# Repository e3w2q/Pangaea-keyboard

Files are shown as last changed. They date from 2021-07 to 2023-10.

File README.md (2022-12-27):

# Pangaea





Parts adjustable keyboard

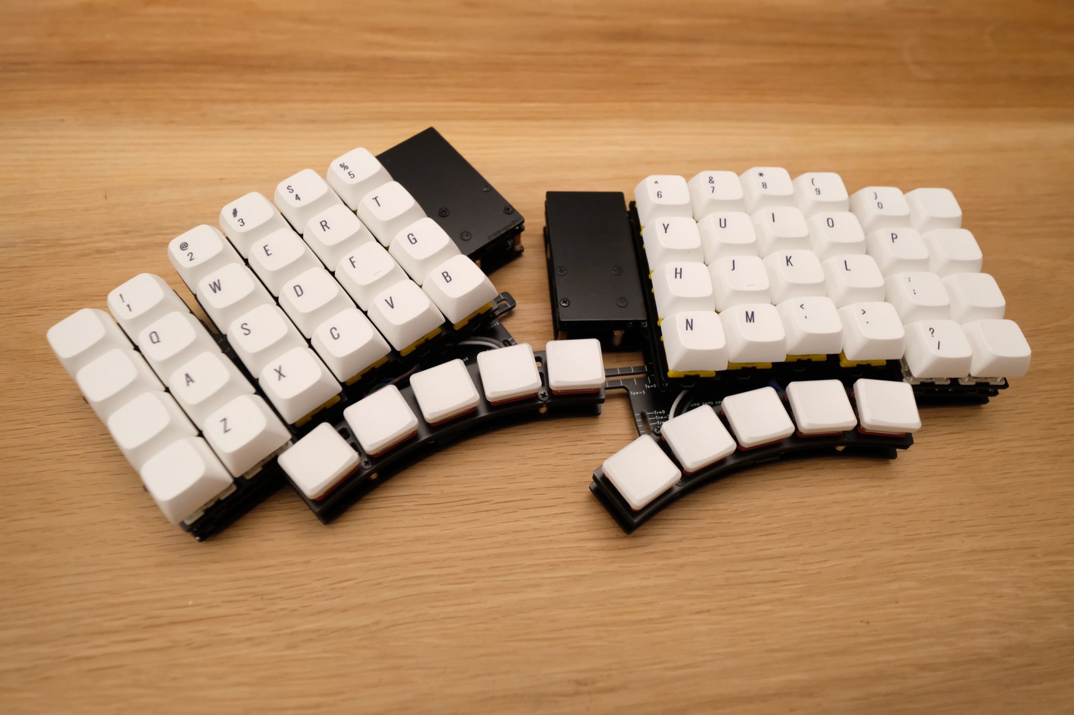
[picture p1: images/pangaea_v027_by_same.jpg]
pangaea_v027_by_same


## What is Pangaea?

Column staggered keyboards differ in the way the columns are shifted and the thumb keys are placed, depending on the designer's assumed finger size and design philosophy.

Pangaea is a column staggered keyboard that allows you to adjust the key layout for the pinky and thumb areas.

https://user-images.githubusercontent.com/50942793/145424793-fb12e412-2e66-4725-97fb-f4ba11a33d6f.mp4

## Link

[ホワイトペーパー](whitepaper_jp.md), [White Paper](whitepaper_en.md)

[ビルドガイド](build_guide_jp.md), [Build Guide](build_guide_en.md)

[パーツリスト](bom_list_jp.md)

[Firmware](firmware/)

[PCB](design/)

[Gerbers](products/)

## License

* firmware: GPLv3
* Garber files: CC-BY-NC
* other files: MIT

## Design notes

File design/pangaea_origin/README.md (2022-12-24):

# Pangaea PCB Data

Some design data are not included.

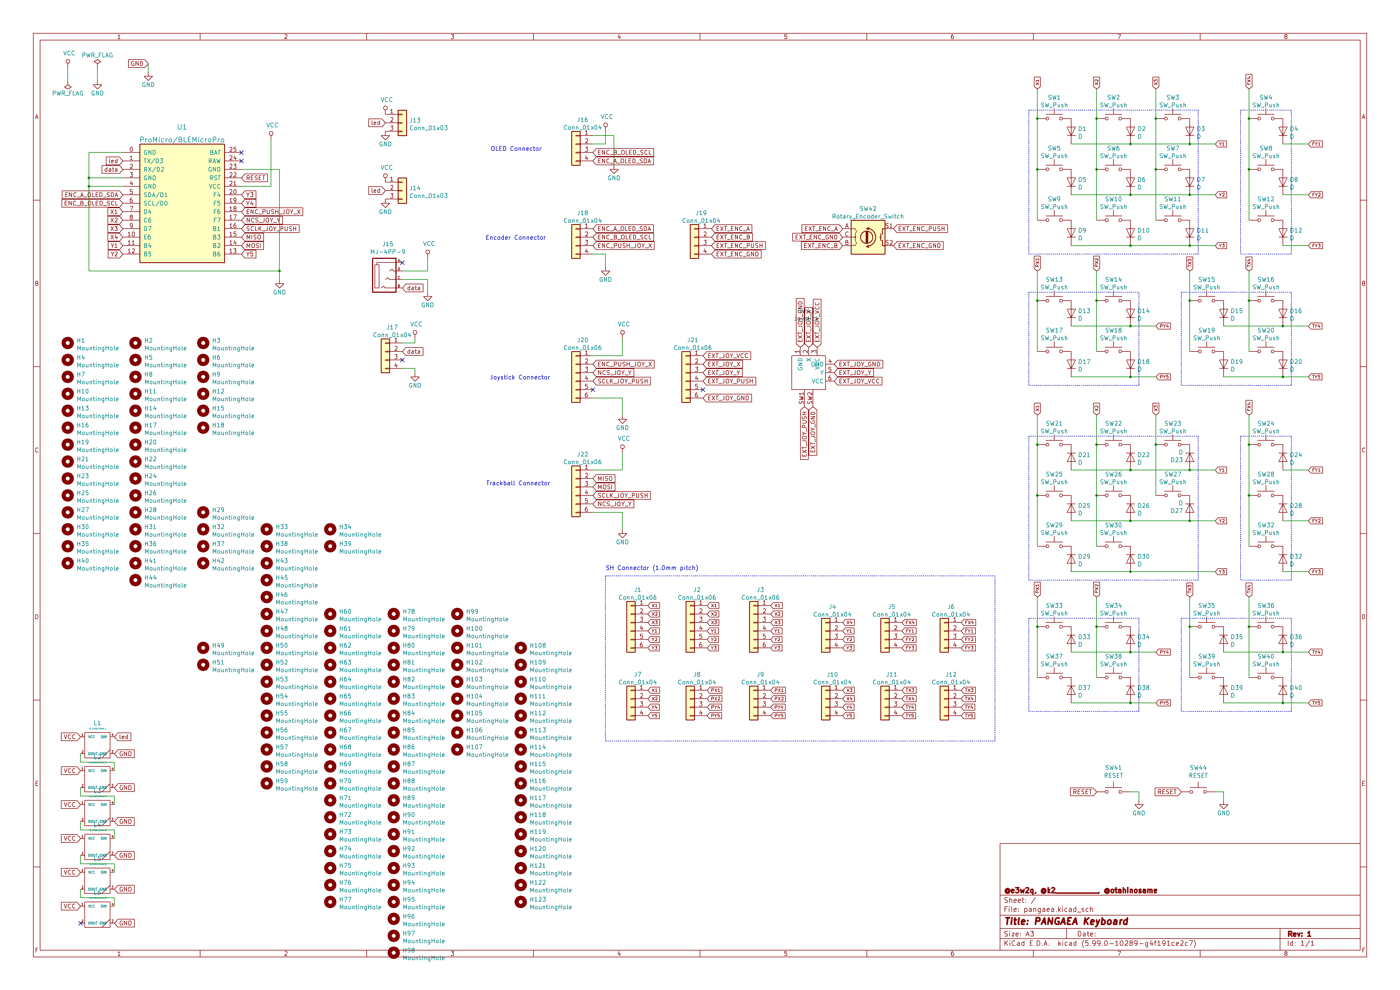
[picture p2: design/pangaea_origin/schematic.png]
Schematic


“Further, we have to be prepared always for the possibility that each new discovery, no matter what science furnishes it, may modify the conclusions we draw.” 

Alfred Wegener, *The Origins of Continents and Oceans*

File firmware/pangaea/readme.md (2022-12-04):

# Panagaea Keybaord

This is a modular type split keyboard consisting of three parts: main keys, pinkeys, and thumb keys. The name comes from the ancient continents, each of which shows a separate continent. As a feature, it has a mechanism to adjust the position of those modules. Furthermore, Pangaea defines specifications for creating extended components so that you can combine components or create new ones.

The firmware is written with QMK.

Keyboard Maintainer:
  [@otahinosame](https://twitter.com/otahinosame), [@e3w2q](https://twitter.com/e3w2q), and [@k2___________](https://twitter.com/@k2___________)

## How to build
```
$ qmk compile -kb pangaea -km default
```

The default keymap is tested with QMK Firmware 0.18.17. (Nov 27, 2022)

Limitations:
 - Only left side rotatay encoder supported.
 - No push button of the rotatay encoder implemented.

## How to flash
```
$ qmk flash -kb pangaea -km default
```

If you want to try to use other keymaps, for example,

```
$ qmk flash -kb pangaea -km otahinosame
```

Please refer the details in keymaps directory.

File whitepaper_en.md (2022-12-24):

Date: 2022/12/24
Keyboard Maintainer: [@otahinosame](https://twitter.com/otahinosame), [@e3w2q](https://twitter.com/e3w2q), and [@k2___________](https://twitter.com/@k2___________)

*Note: This text is an English translation of [White Paper written in Japanese](https://github.com/e3w2q/Pangaea-keyboard/blob/main/whitepaper_jp.md).

# What’s Pangaea?

Pangaea is a keyboard that isolates the key layout into several “islands” and allows the user to move the position of each island freely.   As an island, it is divided into three parts: the main body, the thumb section, and the little finger section.  We named it Pangaea, comparing the movement of a chunk of the key arrangement to the theory of continental drift.

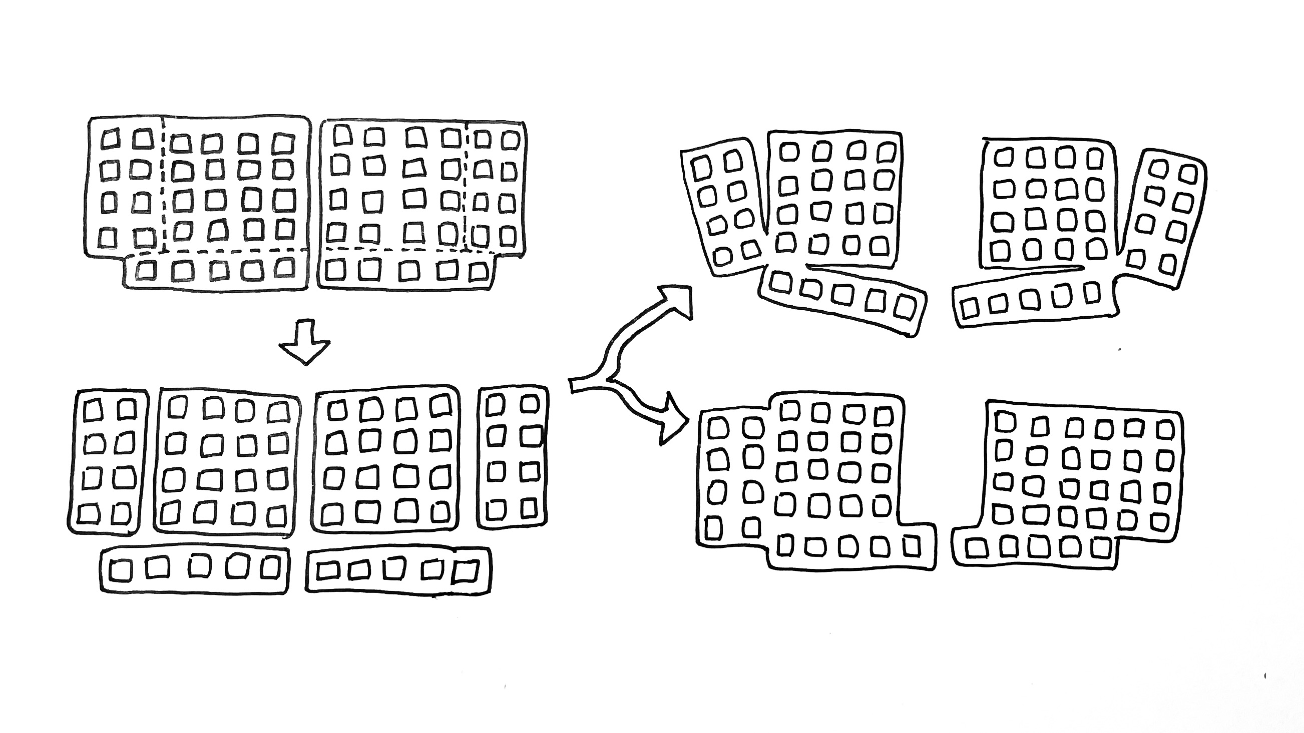
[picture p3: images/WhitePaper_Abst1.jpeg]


# What can it do?

By moving the island, you can adjust the key layout to suit your preference and hand shape. Just as you adjust the seat height and back angle of a chair while checking its comfort, you can adjust the keyboard to a shape that is easy to use while using it.

# Why Pangaea?

What was it made for?
Original experience (by @otahinosame)

There are various column-staggered keyboards, but the differences that interest me are the height of the little finger and the position of the thumb keys. However, you won’t know which one fits you until you try it out. If you want to try a little layout changes in actual usage, it costs a certain money to make it.  I want to at least make sure how high it fits before I buy the kit. (I want to avoid local solutions, I want to avoid bias since I’ve just bought it, I want to actually compare and decide.)

# What kind of things do we want?

I want a keyboard that can be easily adjusted while in use. I want a kit that can easily make keyboards with adjustable key layouts. Everyone wants it! That’s how we came to develop this kit.

# How Pangaea works?

Relative positions of islands are connected with connecting parts. They can be freely movable or fixed. For example, by combining plates with slits on the rails, the position and angle can be continuously adjusted. 

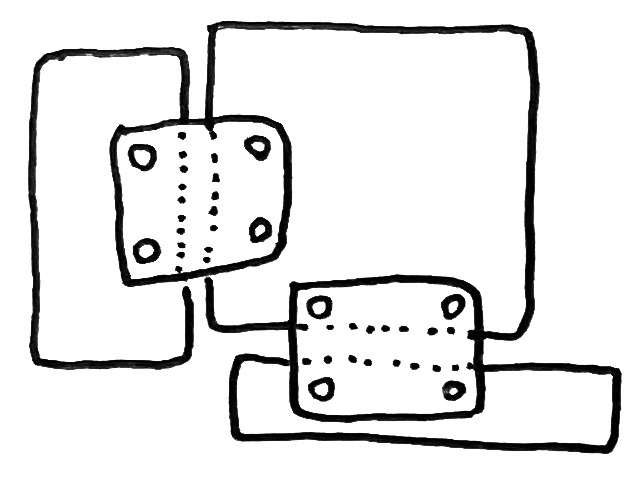
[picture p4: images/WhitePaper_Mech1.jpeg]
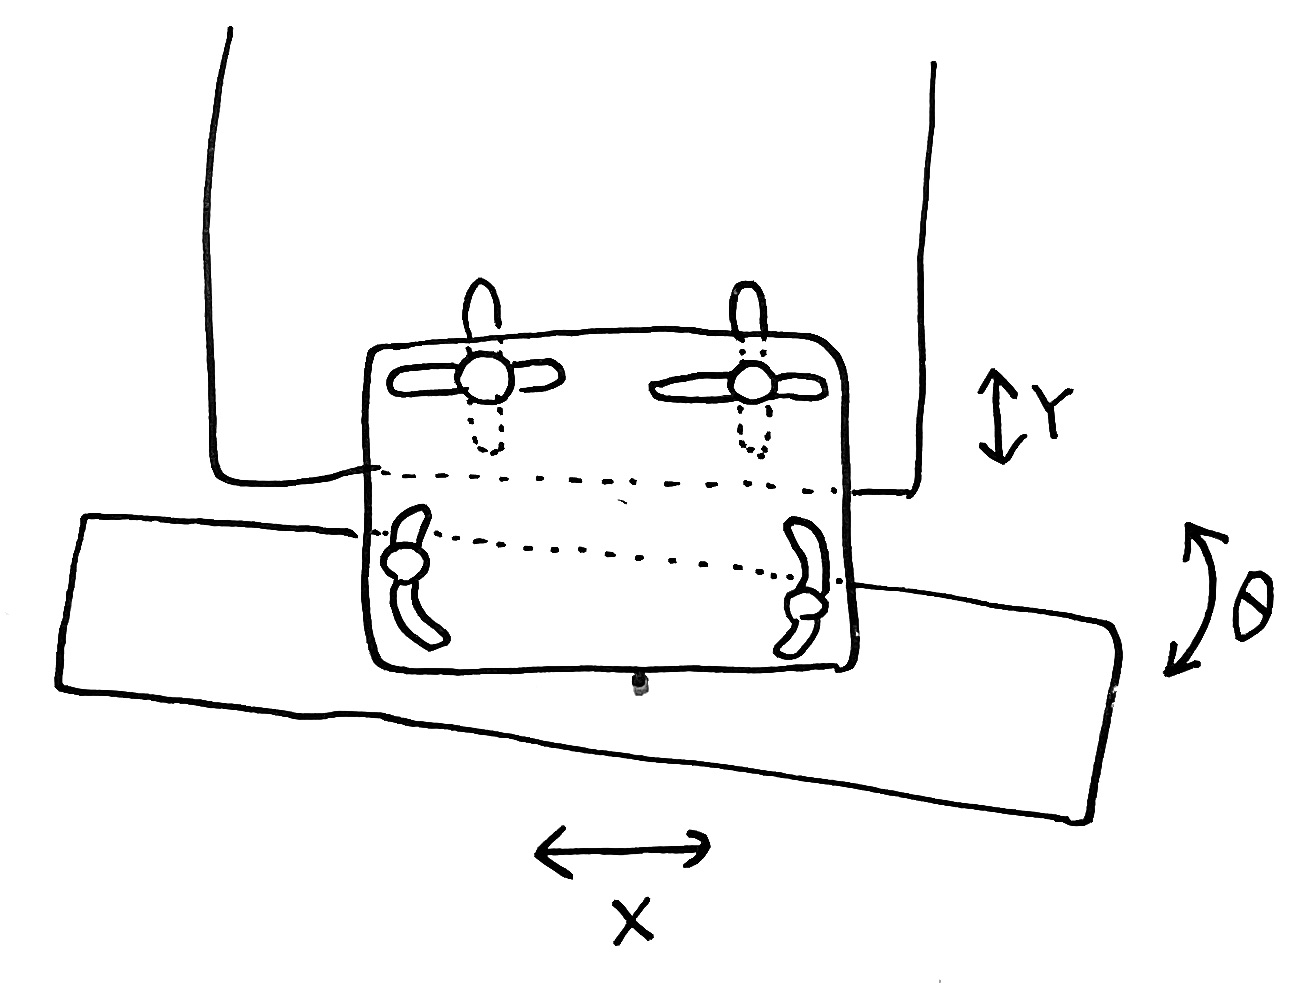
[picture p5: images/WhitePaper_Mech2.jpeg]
    

Electrical connections between islands can be made by using flexible wiring, allowing islands to move while wired together.  Islands can be freely replaced or expanded according to Pangaea specifications. Additional elements can also be connected freely.  The following is the examples of future expansion and support.

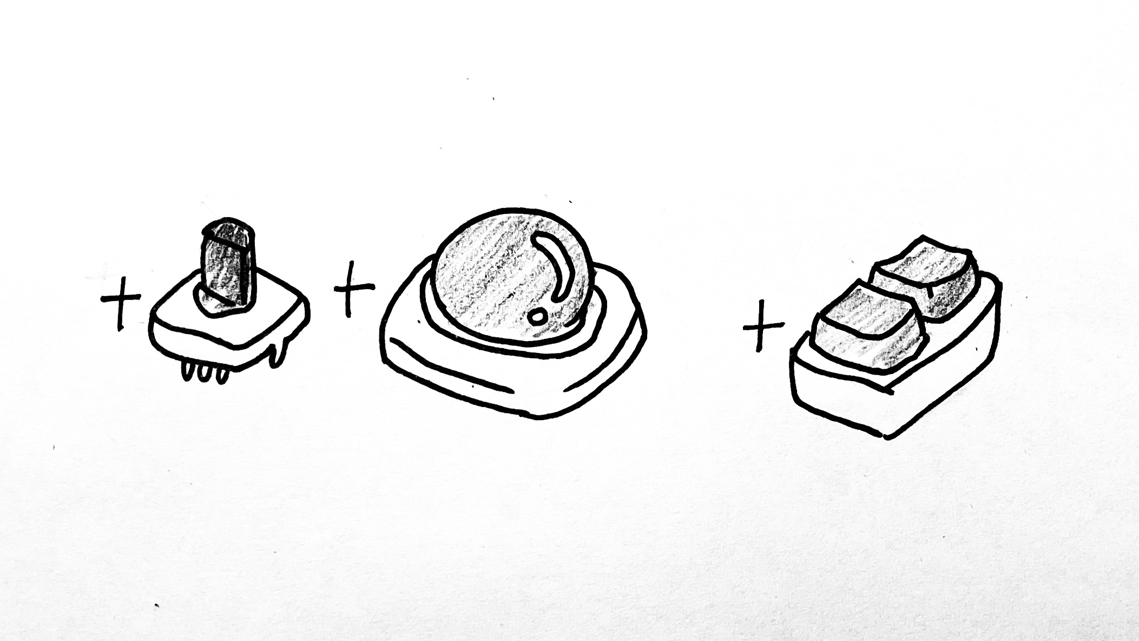
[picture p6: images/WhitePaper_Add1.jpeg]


# Where Pangaea going?

- Hardware
  - Variety of parts with different layouts
  - Row-staggered layout
  - Ortholinear layout
- Usage support
  - Expanded guides for adjusting placement
  - Introduction of custom examples

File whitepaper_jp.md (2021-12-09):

# White Paper on Pangaea keyboard

## What's Pangaea?

### 何なのか

Pangaea (パンゲア) は、キーレイアウトをいくつかの "島" に切り離し、それぞれの島の位置を自由に移動できるようにしたキーボードです。



キー配列のかたまりが移動する様子を大陸移動説になぞらえて、超大陸にちなんでPangaeaと名付けました。

### 何ができるのか

島を動かすことで、個人の好みや手の形（癖、体型）に合わせてキー配置を調整できます。椅子の座り心地を確かめながら座面の高さや背もたれの角度を調整するように、キーボードを使いながら心地よく使える形に調整していくことができます。

## Why Pangaea?

何のために作られたのか

### 原体験 (by otahinosame)

カラムスタッガード配列のキーボードはいろいろあるが、気になる違いは小指の高さと親指のキーの位置。しかし、どれが自分に合うかは試してみないとわからない。数万円かけて作らないと実使用上のテストはできない。せめてどれくらいの高さが合うか確かめてからKitを買いたい。（局所解を避けたい、せっかく買ったのだからバイアスを避けたい、実際に比較して決めたい）

 ### 欲求

使用しながら気軽に調整できるキーボードが欲しい。キー配置を調整できるキーボードを簡単に作れるKitが欲しい。
みんなも欲しいはず！
…という経緯で開発に至りました。

## How Pangaea works?

どうなっているのか

- 島と島の相対位置は、接続パーツで連結。自由に可動・固定ができます。
    - 例えば、レール上にスリットを開けたプレートを組み合わせることで、連続的に位置と角度が調整できます。
    
        

- 島同士の電気的な接続は、ワイヤーなどフレキシブルな配線を使うことで結線したまま島を動かせます。
- 島は規格にしたがって自由に置き換え・拡張ができます。
- 追加の要素も自由に接続可能です。
    - 追加のキー、ロータリーエンコーダー
    - トラックボール（今後検証予定）

    

## Where Pangaea going?

今後の展望

### ハードウェアの展望

- レイアウトの異なるパーツのバリエーション
- ロウ・スタッガード配列
- オーソリニア

### 使いこなしサポート

- 調整手順ガイドを拡充
- カスタム作例の紹介

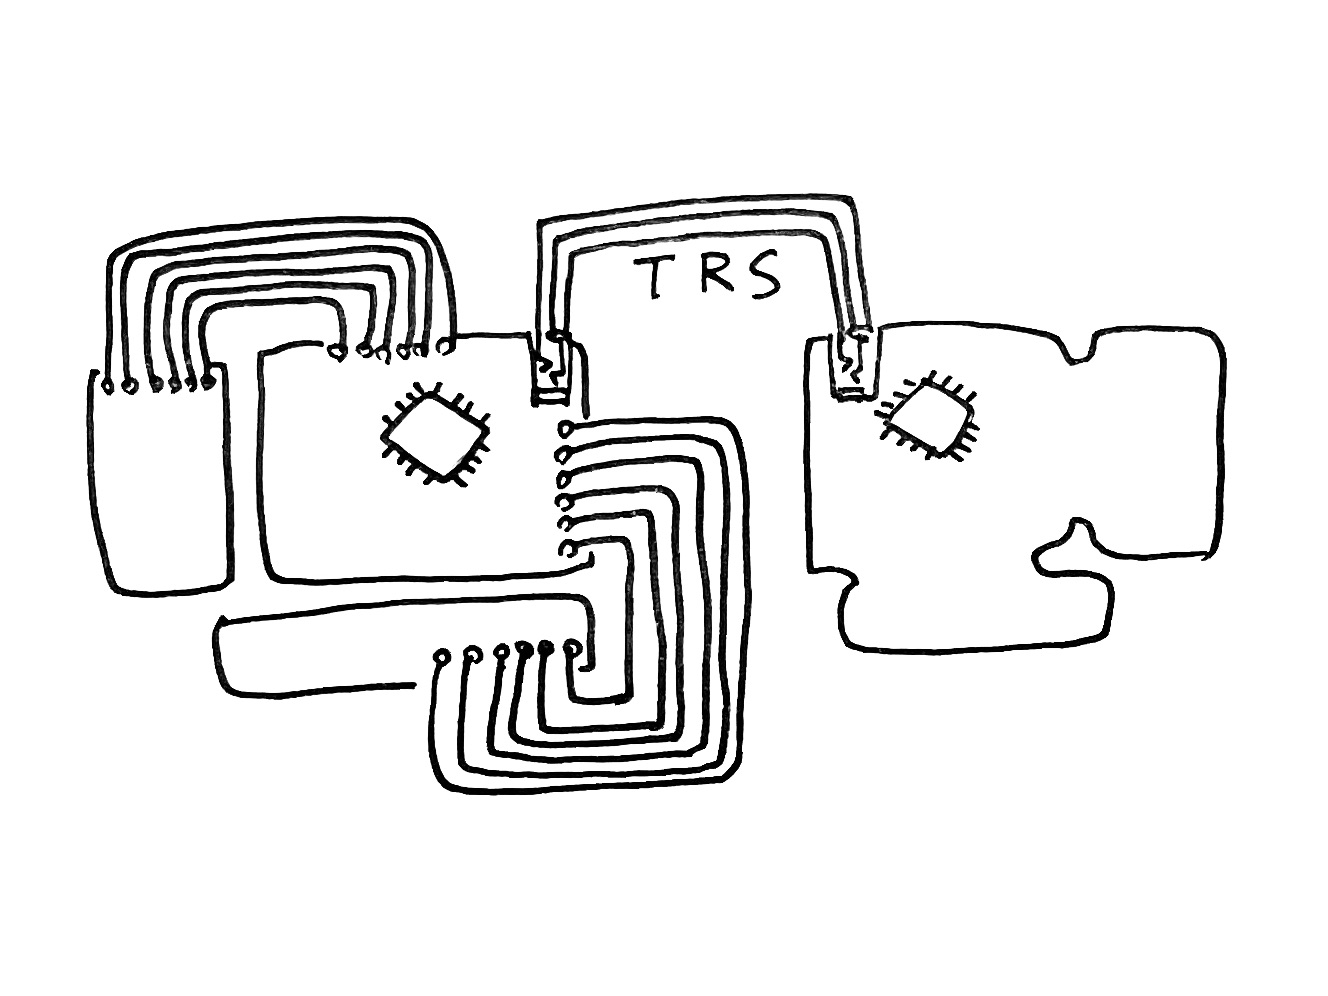
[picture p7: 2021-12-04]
images/WhitePaper_Ele1.jpeg

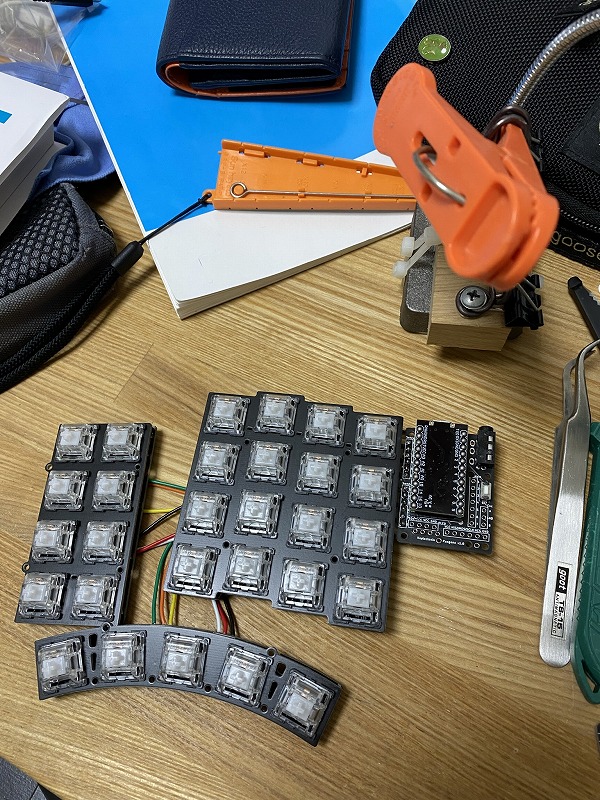
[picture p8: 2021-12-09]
images/e8cf4e5ab07ae1a9450db6237234261d8d0daca476545fba90c7199dbf79572b.jpg

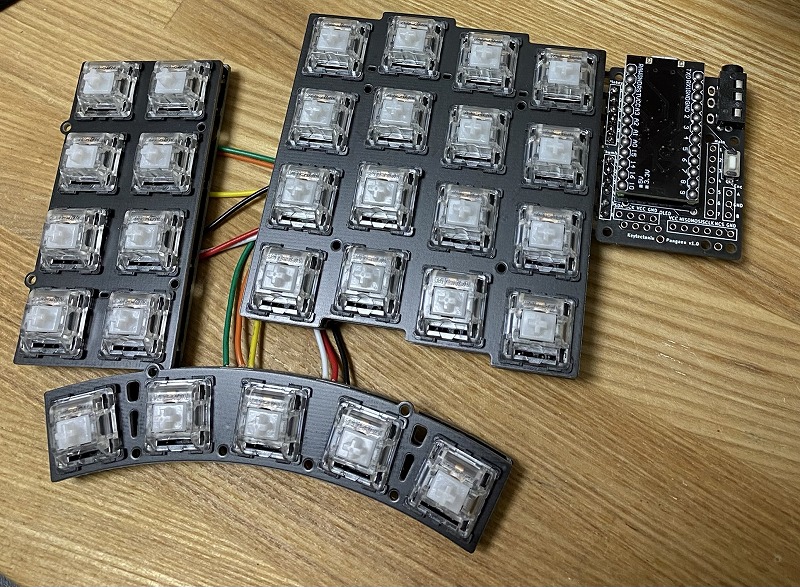
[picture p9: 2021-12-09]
images/ab94f9ed5044287de924d6a61390863da7805d628edc2a0d1da0a6e56190d6b8.jpg

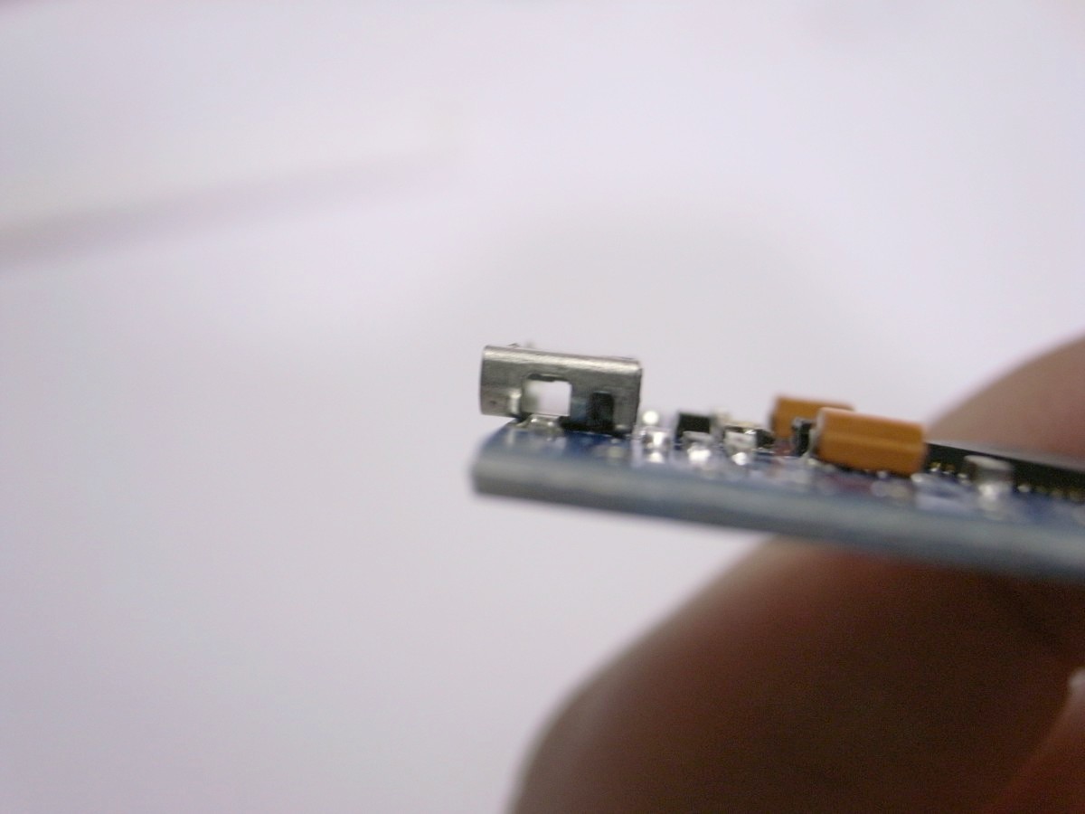
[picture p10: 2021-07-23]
images/promicro_usb_side_hole.jpg

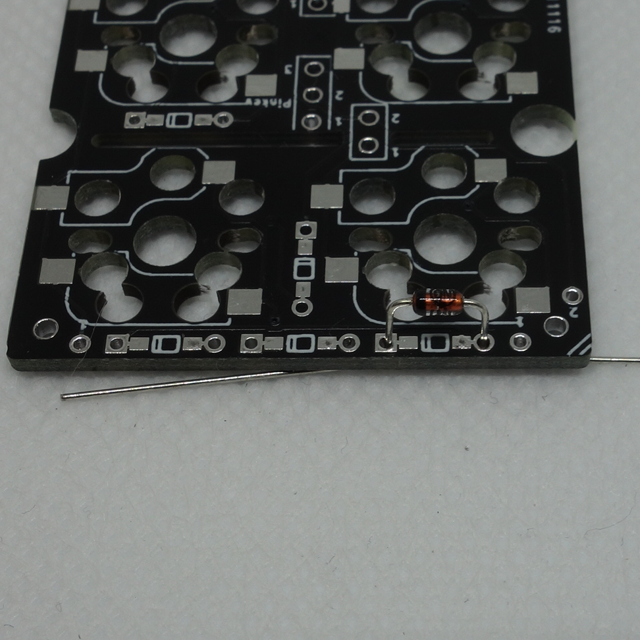
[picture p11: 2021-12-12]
images/f6cd14fc4ce07d51a925ff19d088a67dadaebe4b322aedff619d27195221b481.png

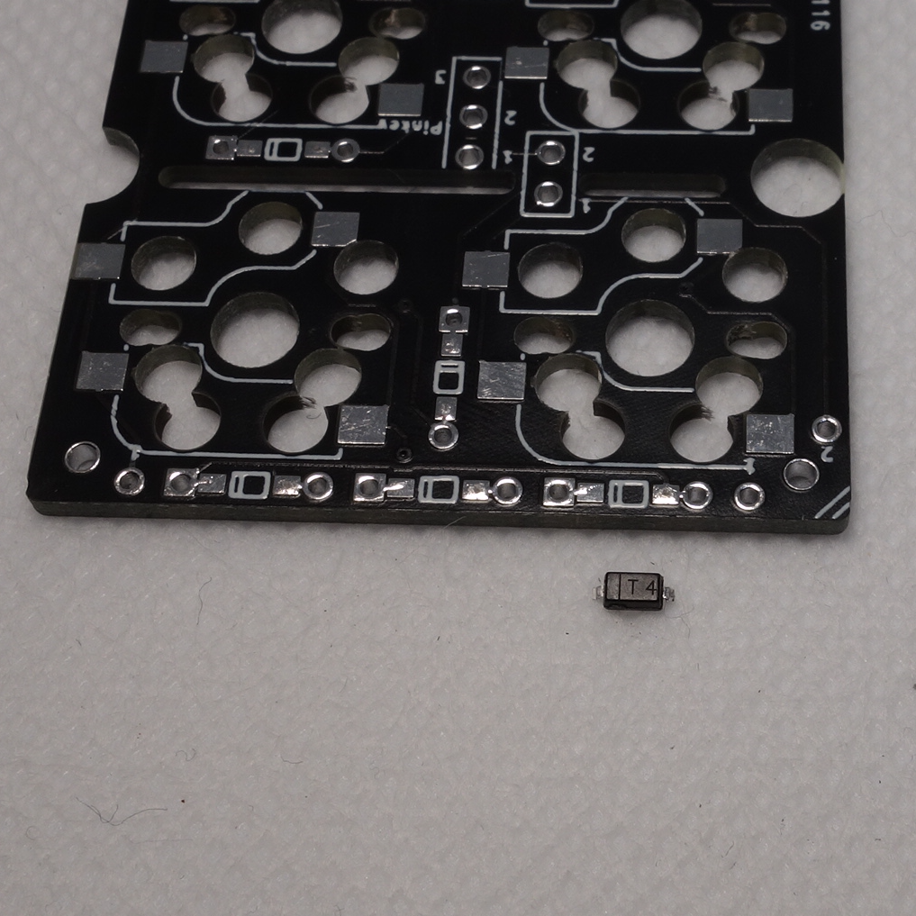
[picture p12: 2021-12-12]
images/abbba190e3abb1a4d159a6759637de540281f7b830526ee0b7b6094bed5aa927.png

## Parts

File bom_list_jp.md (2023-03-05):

# Pangaea パーツリスト

標準構成での組み立てに必要な部品の一覧です。
親指モジュールのキー数を減らす場合はその分のキースイッチ、ソケット、ダイオードが減少します。例えば標準の5キー構成から3キー構成に変更すると、左右でマイナス2ずつでで必要パーツ数は60-2\*2=58となります。
数字行を無くす場合は、左右でマイナス6ずつで、必要パーツ数は60-6\*2=48となります。

## 必須部品
- JST SHコネクタ 4p レセプタクル サイド型
  - <https://akizukidenshi.com/catalog/g/gC-16800/>
    基板用コネクタ　４Ｐ　面実装　サイド型　（５個入）| 秋月電子通商

- JST SHコネクタ 4p プラグ付きケーブル
  - リバースケーブルと呼ばれる、両端のピンアサインが同一になるタイプを使用してください。
  - 互換品がメカトロニクス系の分野で「qwiic」と呼ばれ普及しているようです。
  - <https://akizukidenshi.com/catalog/g/gC-15884/>
    コネクタ付コード　４Ｐ　黒赤青黄　両端コネクタ付き 15cm 秋月電子通商

- ダイオード(スルーホールまたはchip部品) (4x4 + 1 + 4x2 + 1x5) x 2 = 60
  - 1N4148
    - <https://akizukidenshi.com/catalog/g/gI-00743/>
  - SMD
    - <https://shop.yushakobo.jp/products/a0800di-02-100>
  
- スイッチソケット (MXまたは choc 用) 30 x 2 = 60
  - Kailh Hot-Swappable PCB Socket
    - <https://shop.yushakobo.jp/products/a01ps>
    - <https://talpkeyboard.net/items/5e02c5405b120c792616bcf9>
  
- スイッチ  (MXまたは choc 用) 30 x 2 = 60
  - Cherry MX 互換スイッチ、5pin が安定です。お好きなモノで
  - choc スイッチ
    - Google it.
  
- Controller
  - Pro Micro x 2
  - <https://www.switch-science.com/catalog/6228/>
  - 現在の対応マイコンは Pro Micro ですが、今後、Raspbery Pi PicoやRP2040シリーズへの対応も検討されています。
  
- コンスルーピンヘッダ x 2
  - <https://shop.yushakobo.jp/products/31>
  - <https://talpkeyboard.stores.jp/items/5e056626d790db16e2889233>
  - コンスルーを使わず、ピンヘッダをはんだ付けして組み立てることもできます。
  
- Reset switch x 1
  - タクトスイッチ
  - <https://akizukidenshi.com/catalog/g/gP-08074/>
  - 左手側用
  
- Reset switch サイド型 x 1
  - THDP07-060CB <https://akizukidenshi.com/catalog/g/gP-08077/>
  - 右手側用
  
- 3.5mm TRRS ケーブル x 1
  - Google it.
  
- USB ケーブル x 1
  - Google it.
  
- M2 スタンドオフ (長さ8mm, 6mm, 3mm)
  - ASB-2008E
    <https://www.hirosugi-net.co.jp/shop/g/g67/>
  - ASB-2006E
    <https://www.hirosugi-net.co.jp/shop/g/g63/>
  - ASB-2003E
    <https://www.hirosugi-net.co.jp/shop/g/g57/>
  
  - 必要個数はビルドガイドを参照してください。
  
- M2 ネジ (長さ8mm, 3mm)
  - F-0208-E, 8mm
    - <https://www.hirosugi-net.co.jp/shop/g/g36908/>
  - 3mm
  
- ゴム足
  - ダイソー クッションゴム 14個入り など

## オプション部品
以下オプションです

- ワッシャ
  - 使用するとスムーズに可動部分が動きます
  - スプリングワッシャと組み合わせて使うと緩みがなく、かつ可動部分を動かしやすくなります。
  - Google it.
- スプリングワッシャ
  - 使用するとネジが緩みにくくなるため強くおすすめです
  - Google it.
- M1.4 ナット
  - M1.4ナットとネジをボトムプレートに取り付けた物をPCBの支柱として、スイッチソケットが緩みPCBが脱落することを防止できます。
  - [ステンレス鋼,2〜50個,din934 m1 m1.2 m1.4 m1.6 m2 m2.5 m3 m4 m5 m6 m8 m10 m12,黒アルミニウム六角ナット|ナッツ類| - AliExpress](https://ja.aliexpress.com/item/33011176338.html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)
- M1.4 ネジ
  - [2/5/10/50/100個m1 m1.2 m1.4 m1.6 M2 M2.5 M3 M4 m5 m6 m8 DIN7985 304ステンレス鋼クロスプラスラウンドなべスクリューボルト|ネジ| - AliExpress](https://ja.aliexpress.com/item/32948746653.html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)
  - 長さ4mmを使用（上記商品は実測4.3～4.4mm）

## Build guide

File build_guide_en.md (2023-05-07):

# Pangaea keyboard Build Guide

This is a build guide for the Pangaea Keyboard V1.2.  The original Build Guide written in Japanese is [here](build_guide_jp.md).

The intended audience will be those who have assembled keyboard kits before.  If you have never built a keyboard kit or are not confident about assembling one, please expand the "Tips" section and check it out.  (*note from translater: You will find more detailed information.)

The concept of the Pangaea keyboard is explained in [White Paper](whitepaper_en.md).
The firmware is described in the [Firmware](#Firmware) section, and the source code for QMK Firmware is available [here](firmware/).

The Pangaea Keyboard has a wide variety of optional features that allow you to select the configuration of your choice.  This build guide describes the assembly procedure for a standard configuration. <BR/>*note:  Please refer to [Optional features](#optional-features) for more information on optional features.

- [Pangaea keyboard Build Guide](#pangaea-keyboard-build-guide)
  - [Preparation](#preparation)
    - [Understanding the structure](#understanding-the-structure)
    - [Configuration options](#configuration-options)
    - [Required parts](#required-parts)
  - [Assembly](#assembly)
    - [Assemble the movable Bottom Plate](#assemble-the-movable-bottom-plate)
    - [Assemble the Main Module](#assemble-the-main-module)
    - [Assemble Pinky Module](#assemble-pinky-module)
    - [Assemble Thumb Module](#assemble-thumb-module)
    - [Install Key switches](#install-key-switches)
    - [Combining Modules](#combining-modules)
  - [Firmware](#firmware)
    - [Flash the firmware](#flash-the-firmware)
    - [Operation check](#operation-check)
  - [Final steps](#final-steps)
    - [Rubbter feet](#rubbter-feet)
    - [Keycap](#keycap)
    - [TRRS cable](#trrs-cable)
    - [Completed](#completed)
  - [Adjustment](#adjustment)
    - [Adjust key layout](#adjust-key-layout)
    - [Modifying the key map](#modifying-the-key-map)
  - [Optional features](#optional-features)
    - [Kailh Choc v1 switches](#kailh-choc-v1-switches)
    - [Solder switches on PCB without sockets](#solder-switches-on-pcb-without-sockets)
    - [Height adjustment](#height-adjustment)
    - [Tilts and Tents](#tilts-and-tents)
    - [Preventing PCBs from falling out](#preventing-pcbs-from-falling-out)
    - [Tape LED](#tape-led)
    - [Delete number rows](#delete-number-rows)
    - [Rotary encoder](#rotary-encoder)
    - [Delete rotary encoder part](#delete-rotary-encoder-part)
    - [Delete the extended key](#delete-the-extended-key)
    - [Seprate MPU board](#seprate-mpu-board)
    - [Compatible modules](#compatible-modules)
  - [Further modifications](#further-modifications)
    - [Adding keys](#adding-keys)
    - [Adding rotary encoders](#adding-rotary-encoders)
    - [Adding displays](#adding-displays)

## Preparation

This section describes the preparation before the assembly process.

[Preparation](#preparation) > [Assembly](#assembly) > [Firmware](#firmware) > [Final steps](#final-steps) > [Adjustments](#final-steps) (> [Optional Features](#optional-features) > [Further Modifications](#further-modifications))

* [Understanding the structure](#understanding-the-structure)
* [Configuration options](#configuration-options)
* [Required parts](#required-parts)

### Understanding the structure

First, let's look at the the structure and terminology.
Hereafter, when the engraved side of the keycap is facing up, the upper side is called the front side and the lower side is called the back side.

When the keyboard is assembled, it looks like the picture.

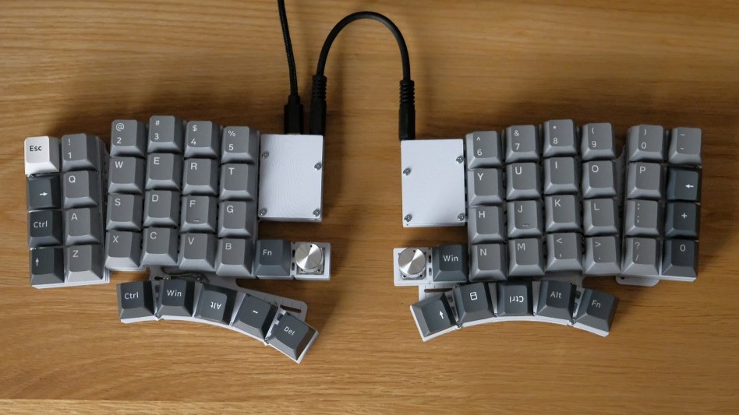
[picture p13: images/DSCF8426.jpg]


One of the most unique features of the Pangaea Keyboard is the ability to move the positions of the thumb and pinky plates  Not only can you assign what keys to what switches in the software, but you can also adjust the physical key layout.  For example, you can adjust the position of the thumb to shift slightly, or adjust the angle slightly to fit your finger.

The Pangaea Keyboard is divided into three modules of parts for its mechanical adjustment mechanism.

* The largest one in the center is defined as the Main Module.
* The vertical rectangles at the left and right ends are defined as Pinky Modules.
* The lower arc-shaped one is defined as Thumb Module.
* The plate with an open slit between them is defined as Bridge Plate.
* In addition, the modules are connected by cables to transmit electrical signals between modules.

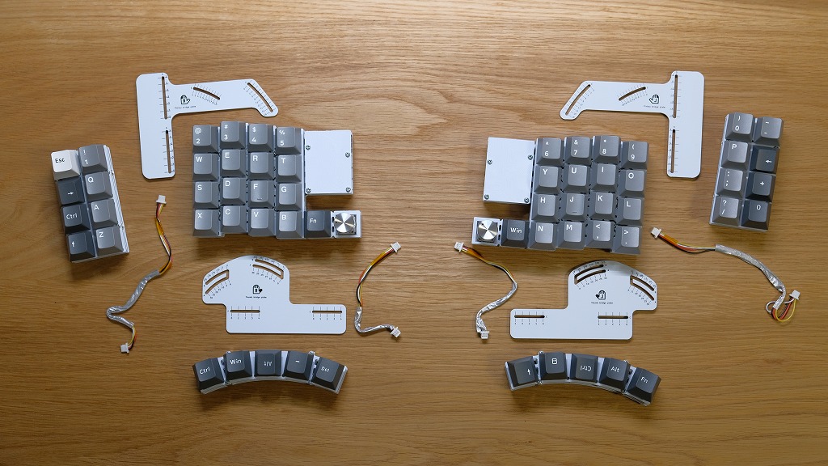
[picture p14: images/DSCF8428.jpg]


### Configuration options

The Pangaea keyboard has a variety of optional features.  This build guide describes the assembly procedure for a standard configuration.
*note: For more information on optional features, please refer to [Optional features](#optional-features)

The standard configuration described in this build guide is as follows,

* [x] Use Cherry MX compatible switches
* [x] Use switch sockets
* [x] Use through-hole diodes
* [x] Use LEDs (optional)
* [x] Use rotary encoder (optional)
* [x] Solder ProMicro directly to PCB with the pin headers
* [x] Use a vertical (normal) reset switch
* [x] Use the pre-built VIA-compatible firmware
* [x] Use five thumb keys for both hands
* [x] Do not separate the number line, rotary encoder, expansion keys, and ProMicro section
* [x] No other modifications

*note: If you choose an option that differs from the standard configuration, please read the assembly instructions properly before proceeding.

### Required parts

| Category | # | comment |
| --- | ---- | --- |
| --- **PCBs** --- | | |
| Main module PCB for left side | 1 | |
| Main module PCB for right side | 1 | |
| Main module cover plate for ProMicro | 2 | |
| Main module switch plate | 2 | Common parts for both side |
| Main module bottom plate | 2 | Common parts for both side |
| Pinky module PCB | 2 | Common parts for both side |
| Pinky module switch plate | 2 | Common parts for both side |
| Pinky module plate | 2 | Common parts for both side |
| Thumb module PCB | 2 | Common parts for both side |
| Thumb module switch plate | 2 | Common parts for both side |
| Thumb module bottom plate | 2 | Common parts for both side |
| Pinkey bridge palte | 2 | Common parts for both side |
| Thumb bridge plate | 2 | Common parts for both side |
| --- **Electric patrs** --- | | |
| ProMicro or compatible | 2 | ATmega32U4, 5V |
| Pin header | 4 | Included with ProMicro |
| Tact switch for reset | 1* | *It can also be omitted.<BR/>(It cannot be installed on the right side.)|
| 3.5mm TRRS jack | 2 | |
| Diodes | 60 | |
| Switch socket for hotswap | 60 | |
| Cherry MX compatible key switch | 60 | |
| SK682MINI-E (LED) | 12 | optional, it can be omitted. |
| Rotary encoder (potentiometer) | 2* | optional, it can be omitted |
| JST SH 4pin reverse cable 10cm length | 2* | Connection between main and rotary encoder, optinal |
| JST SH 4pin reverse cable 10cm length | 2 | Connection between main and pinky module |
| JST SH 4pin reverse cable 15cm length | 2 | Connection between main and thumb modules |
| JST SH 4pin connector, surface mount side type | 8 | |
| --- **Screws** --- | | |
| M2 double thread hexagonal spacer, 8mm length | 24 | Supporting switch plates, 12 for one-hand |
| M2 double thread hexagonal spacer, 3mm length | 4 | PCB support around ProMicro, 2 pieces for one-hand |
| M2 double thread hexagonal spacer, 6mm length | 8 | Supporting ProMicro covers, 4 pieces for one-hand |
| M2 screw, 8mm length | 24 | Fixing the bottom plate, 12 for one-handed |
| M2 screw, 3mm length | 48 | Fixing the switch plate, PCB and ProMicro cover, 24 for one-hand |
| --- **Others** --- | | |
| USB cable | 1 | Connection between ProMicro and your PC |
| TRRS cable | 1 | Connecttion between the left module and right modules |
| Key caps | 60 | All 1u size |
| Knob for rotary encoder | 2 | Up to 19mm in diameter |
| Tapes | - | To hold cables together, optional |
| Insulating tape | - | To secure the cable to the PCB for easier routing, optional  |
| Rubber foot, 2.2mm thick | 10 | Attach to bridge plate |
| Rubber foot, 3.8mm thick | 20 | Attach to bottom plate |

Please refer to [Parts List (BOM)](bom_list_jp.md) for detailed model numbers and availability of each part.  Please use JST SH cables with the same pin assignments on both ends, reverse cable.

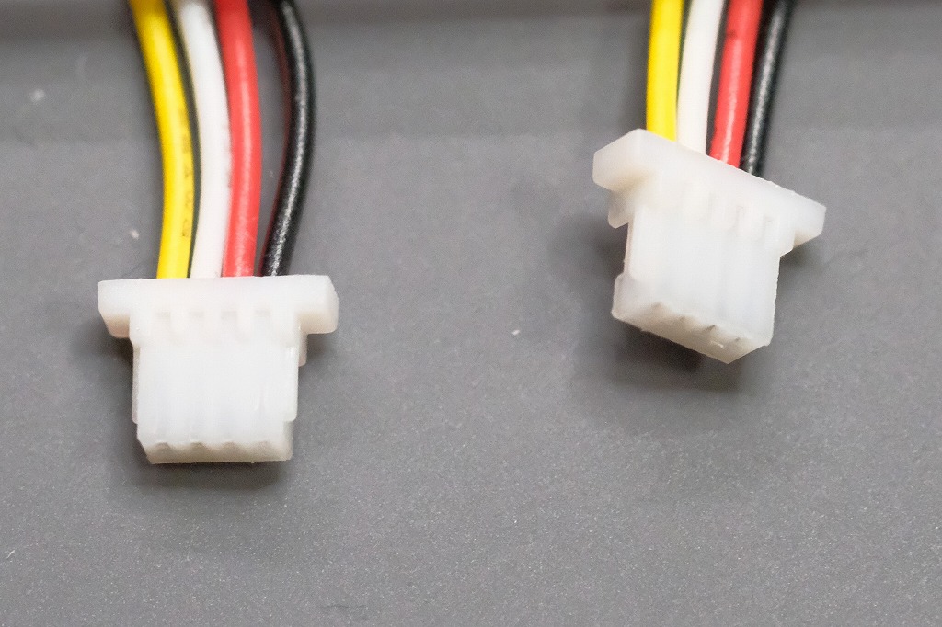
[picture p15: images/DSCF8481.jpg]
sh-cable


The type and number of components required may vary depending on the option selected.
*note: Please refer to [Optional features](#optional-features) for more information about optional features.

Here is a photo of all the circuit boards lined up. Make sure there are no shortages.

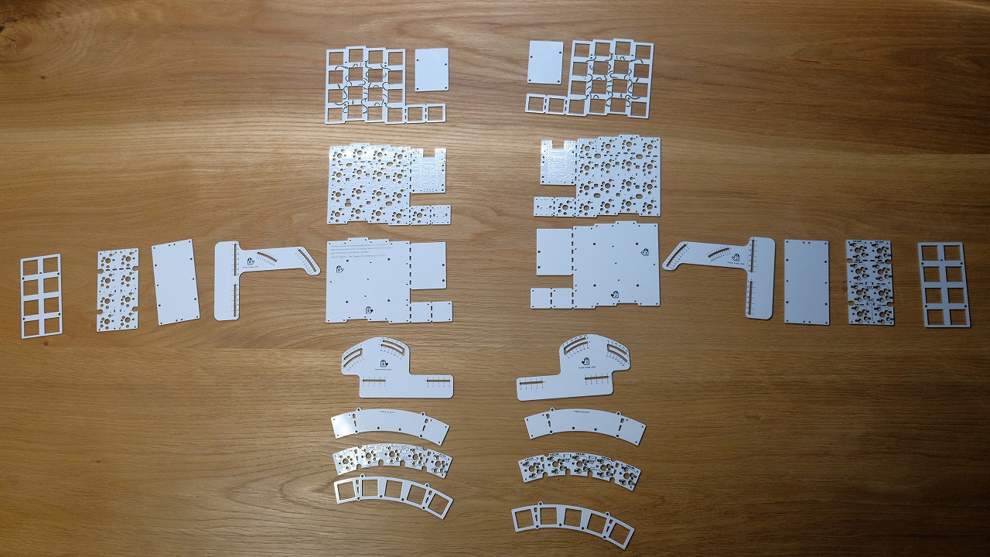
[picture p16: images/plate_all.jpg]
all-parts


* Main Module PCB has different parts on the left and right sides.
* Pinky and Thumb Modules are the same on the right and left hand sides.
* Main Module switch plate, Main Module bottom plate, and Bridge Plate are the same on the left and right sides, but the orientation used is different.
  * Use them in the orientation where the left hand side is the one with the "L" mark when viewed from the **reverse side** and the right hand side is the one with the "R" mark when viewed from the **reverse side**.

## Assembly

[Preparation](#preparation) > [Assembly](#assembly) > [Firmware](#firmware) > [Final steps](#final-steps) > [Adjustments](#final-steps) (> [Optional Features](#optional-features) > [Further Modifications](#further-modifications))

* [Assemble the movable Bottom Plate](#assemble-the-movable-bottom-plate)
* [Assemble the Main Module](#assemble-the-main-module)
* [Assemble Pinky Module](#assemble-pinky-module)
* [Assemble Thumb Module](#assemble-thumb-module)
* [Install Key switches](#install-key-switches)
* [Combining Modules](#combining-modules) 
* 
Even if you make a mistake in the order of assembly, it will not be irreversible. Please proceed with the assembly with ease.

### Assemble the movable Bottom Plate

First, assemble the movable Bottom Plate, which is the best part of the Pangaea Keyboard, the variable mechanism.

Then, attach 8mm screws and 8mm spacers at the positions circled in red. From the back side, stack the screw heads, Bridge Plate, Bottom Plate, and spacers in this order.

The finished keyboard will look like the picture below. It contains a mechanism that allows the pinky and thumb modules to be freely adjusted in relation to Main Module.

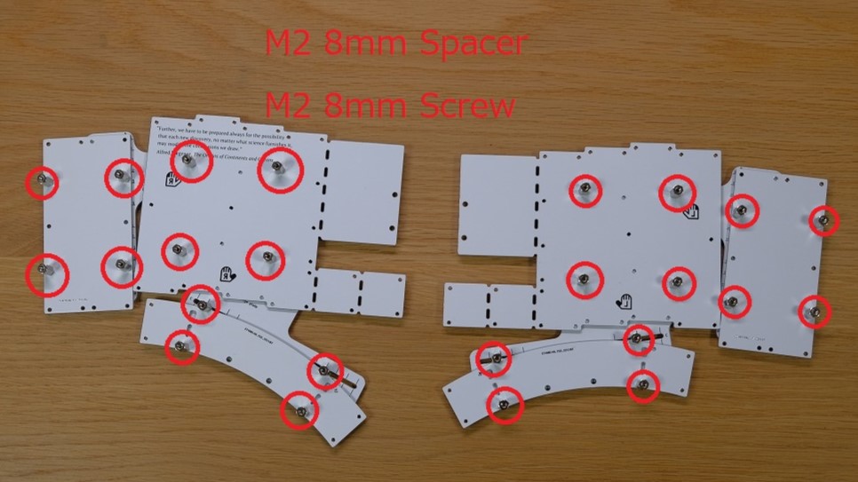
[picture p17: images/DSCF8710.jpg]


The picture below shows it from the back.

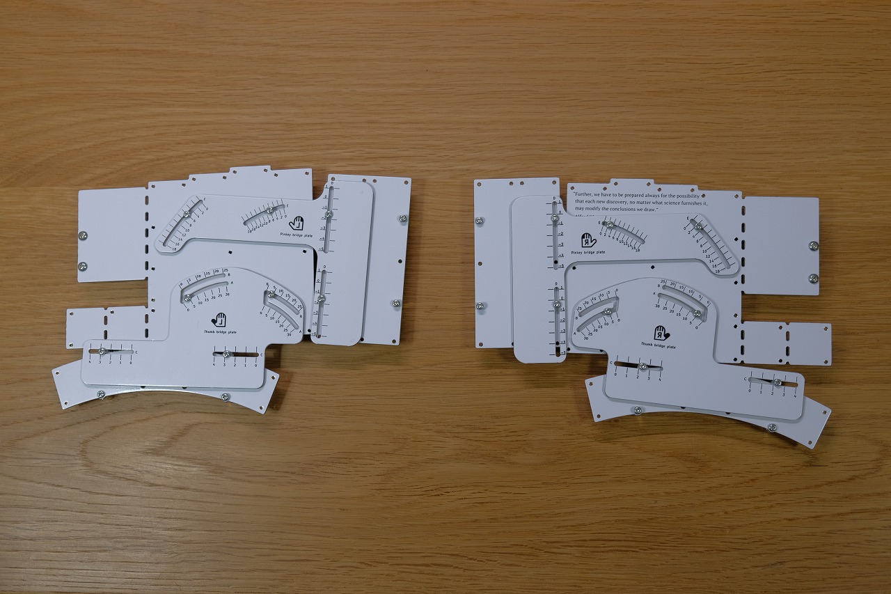
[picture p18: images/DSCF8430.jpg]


<details>
<summary>Tips: Using washers</summary>
<div>
For smoother operation after assembly, we recommend using washers and spring washers for moving parts. If you screw directly, the screws will loosen easily, and it will be inconvenient to use a screwdriver to screw in the screws for adjustment. By using washers and spring washers, the parts can be moved even when the screws are tightened to some extent, which makes adjustment after assembly easier.
</div>
</details>

*note: The lengths of screws and spacers used for assembly are shown in the figure below.

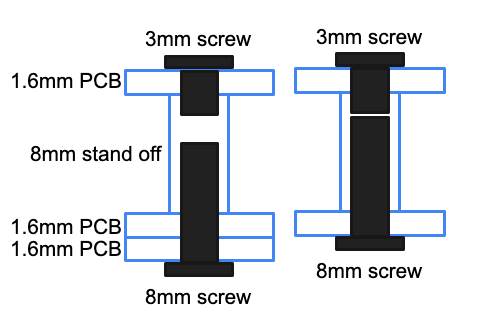
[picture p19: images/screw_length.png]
screw


### Assemble the Main Module

Components are installed on the PCB of each module, starting with Main Module.

[Preparation](#preparation) > [Assembly](#assembly) > [Firmware](#firmware) > [Final steps](#final-steps) > [Adjustments](#final-steps) (> [Optional Features](#optional-features) > [Further Modifications](#further-modifications))

The following components are installed in the Main module.

* [LED (optional)]
* [SH connector]
* [Diode]
* [Switch socket]
* [ProMicro]
* [TRRS jack]
* [Reset switch (optional)]

#### LED (Optional)

Solder the LEDs to the **reverse** side of the PCB, with the **glowing side** of the LED facing outward.  The microcontroller-embedded LEDs are sensitive to high temperatures, so lower the soldering iron temperature. 250°C or lower is recommended.

The LEDs are oriented for installation.  Align the diagonally cut leg of the LED terminal with the triangular mark on the PCB (red line).

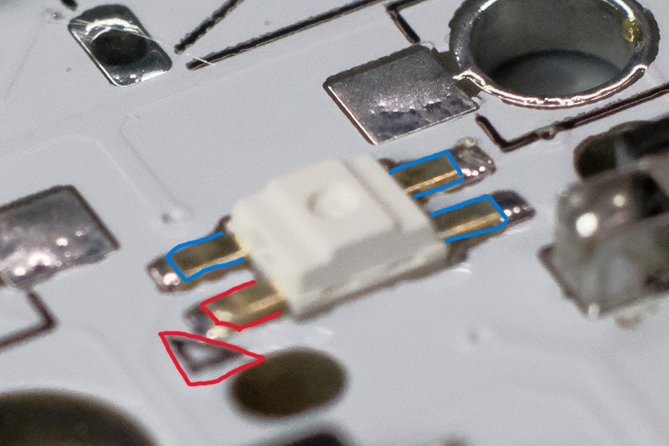
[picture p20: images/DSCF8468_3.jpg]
 

#### SH connector - receptacle

Solder the receptacle of the SH connector to the **back** side of the PCB. This is somewhat difficult, so do it carefully. Attach the connectors for the pinky module and the thumb module, respectively.

If you use a rotary encoder is used, also solder the SH connector for the rotary encoder.

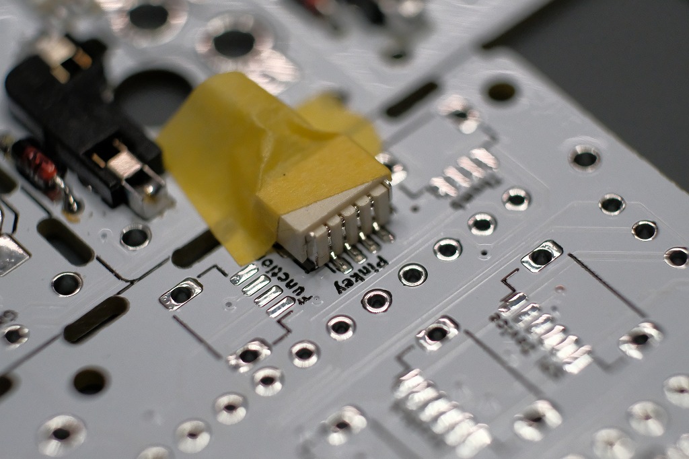
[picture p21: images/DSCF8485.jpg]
 

Pour solder into the through-holes from the back side and solder the fixing feet on both ends of the SH connector.
(Translator's note: If you forget to do this, the connector may come off due to lack of strength when inserting or removing the cables.)

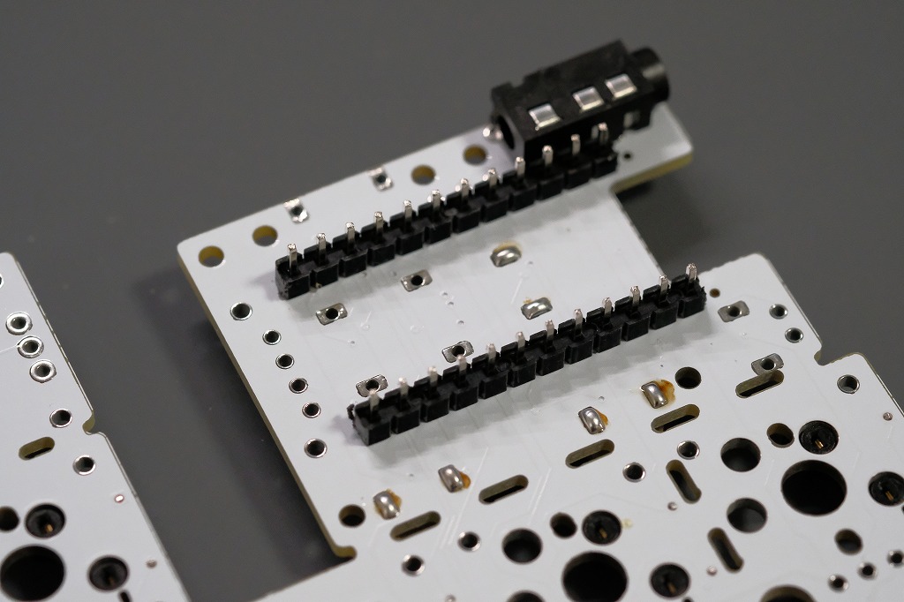
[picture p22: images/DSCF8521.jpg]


#### Diode

Solder the diode to the **back** side of the PCB.

Orient the diode so that the white line on the PCB (or the black line if the PCB is white) aligns with the black line on the diode.

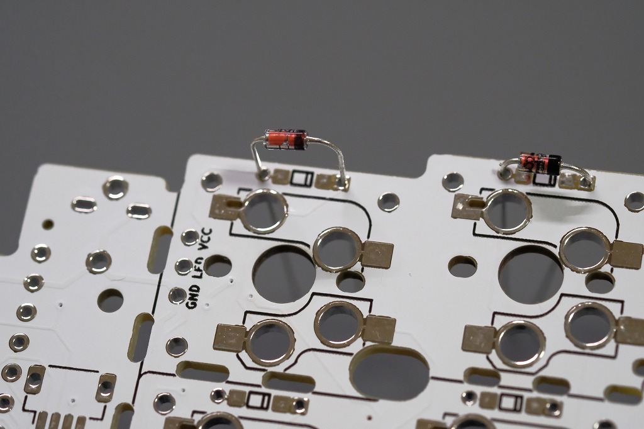
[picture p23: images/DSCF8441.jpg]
 

When using Surface Mount Device (SMD) diodes, align the wires of the SMD diode with the wires on the PCB. In the example in the photo, the left wire marked T4 is aligned with the wire on the PCB.

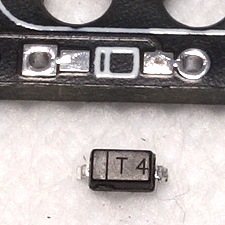
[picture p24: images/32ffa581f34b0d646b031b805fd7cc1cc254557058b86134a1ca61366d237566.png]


This is a view of Main Module PCB for the left hand side from the back. We will now assemble the left one first.

#### Switch socket

The switch socket is similarly soldered to the **back** side of the PCB.  If Cherry MX compatible switch is used, install the socket on the top side.

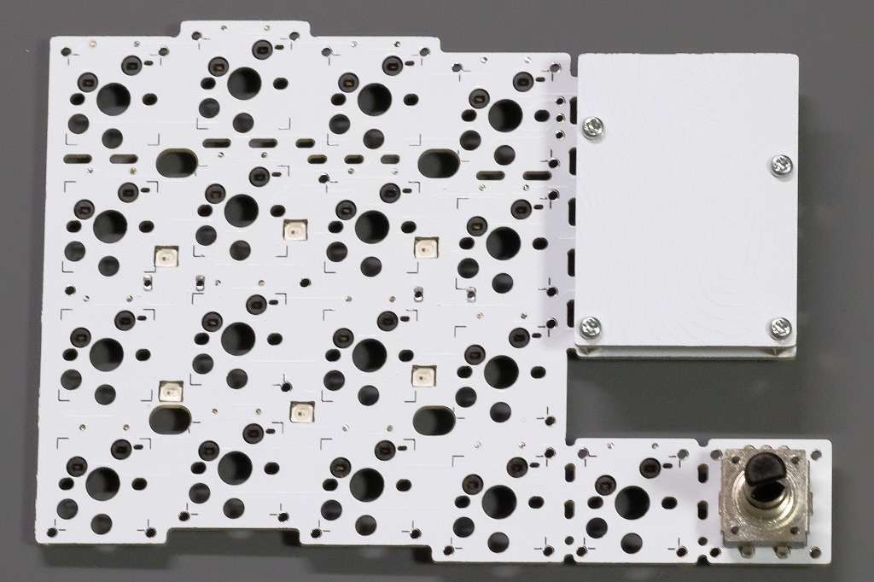
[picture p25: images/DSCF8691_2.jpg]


#### Reset switch

Solder from the **Surface** side of the PCB.
*note: The reset switch cannot be installed on the right hand side. (When resetting, short the through-hole with tweezers, etc. instead of pressing the reset switch.)

#### 3.5mm TRRS jack

Solder from the **Surface** side of the PCB.

#### Pro Micro

Mount the ProMicro on the **front** side of Main Plate PCB with the ProMicro facing down, i.e., the smooth side of the ProMicro is facing up and the side with the various components on it is hidden.

*note: If you want to use the spring pin header, please search for "ProMicro spring pin header". In case of Japan, Yousha Kobo's materials are easy to understand.[コンスルー（スプリングピンヘッダ）の取り付け方を教えて下さい – 遊舎工房サポートサイト (zendesk.com)](https://yushakobo.zendesk.com/hc/ja/articles/360044233974-コンスルー-スプリングピンヘッダ-の取り付け方を教えて下さい)
*note from translator(I'm afraid this is written in Japanese only.)

First, insert the ProMicro supplied pin headers into the PCB. Insert the long one with the short side up.



The back side pops out like this.

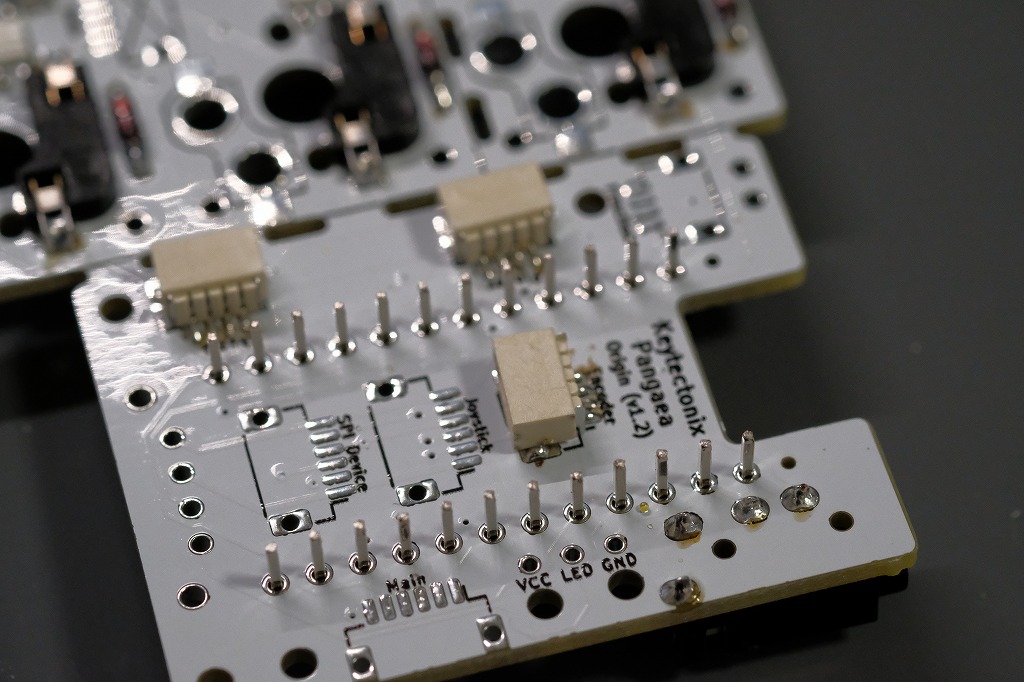
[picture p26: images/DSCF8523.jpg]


Next, ProMicro is layered on top.

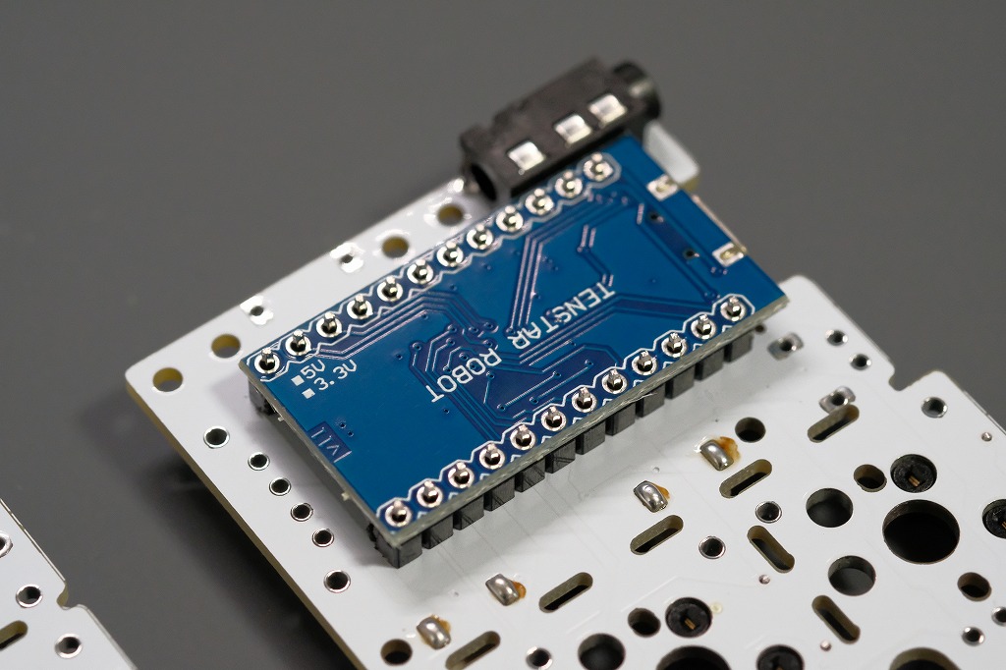
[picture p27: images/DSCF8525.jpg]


Solder the ProMicro and pin headers. Be careful not to bridge the solder with adjacent pins.

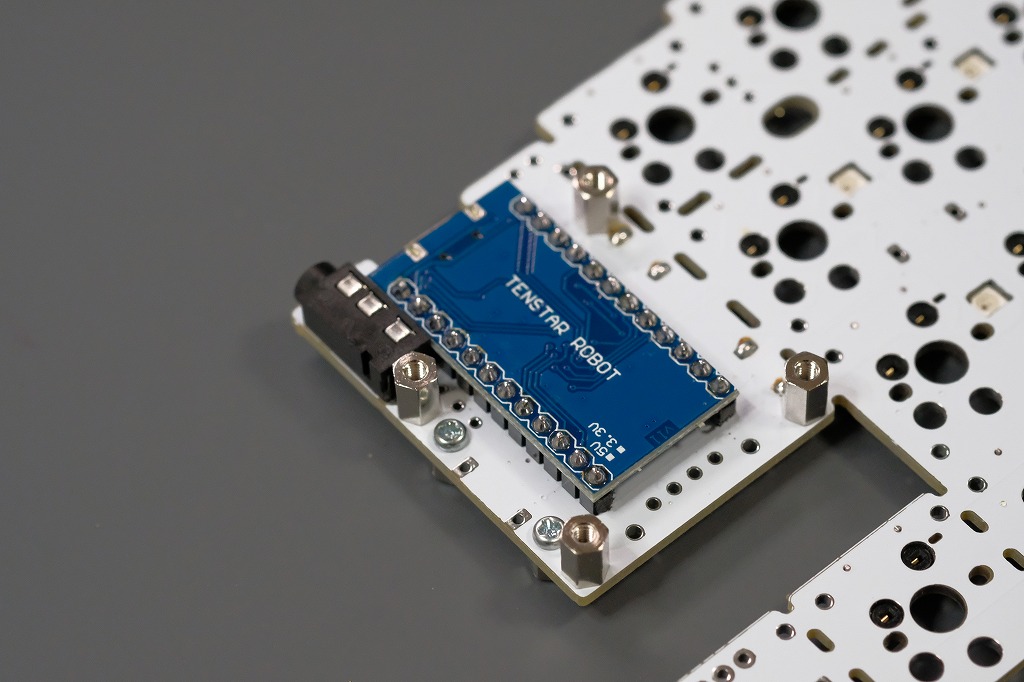
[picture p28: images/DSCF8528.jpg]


Then, use nippers to cut the pin headers that stick out on the back side into short pieces, and solder the pin headers to the Pangaea Main Plate PCB.

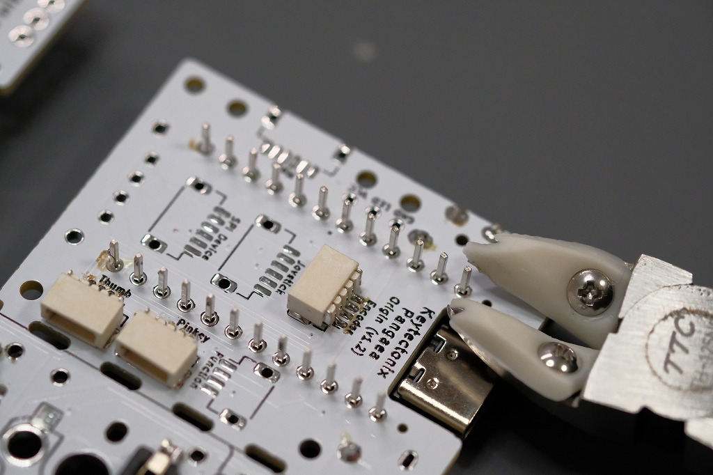
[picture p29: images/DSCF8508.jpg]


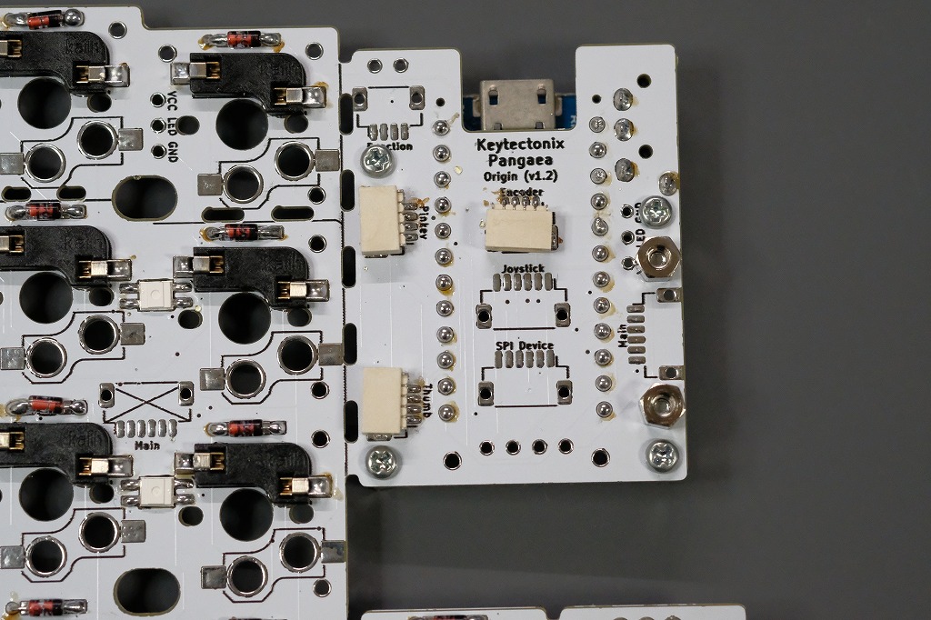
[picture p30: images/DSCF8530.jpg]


*note: When cutting pin headers, be very careful not to let the cut ends fly off.

#### Screw down the standoffs that support the ProMicro

Install M2 3mm screws and M2 3mm spacers at the positions indicated by the light blue circles. This spacer is used to support around the ProMicro on the PCB.  It can be combined with the bottom plate in a later process.

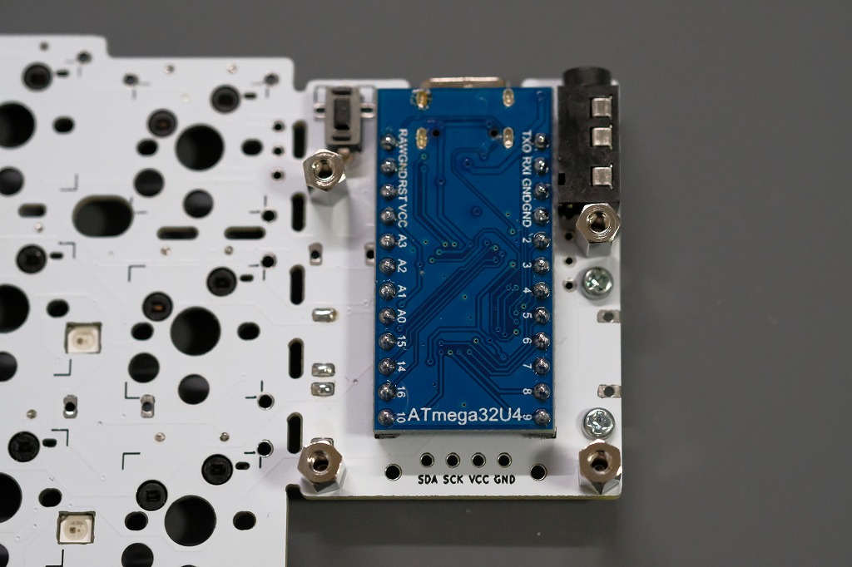
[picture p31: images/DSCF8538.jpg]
 

The figure below shows it from the back.



#### ProMicro cover

Install M2 3mm screws and M2 6mm spacers on the **front** side of Main Module PCB; insert M2 3mm screws from the backside of the Main Module PCB to secure.
Place the cover plate over the Pro Micro and secure with M2 3mm screws in 4 places.  The plate has two sides, so be sure to align the spacers and cover with each other.

#### Rotary Encoder (option)

Solder the rotary encoder.  If you use a toray encoder with a push switch, solder the terminals of the switch as well.

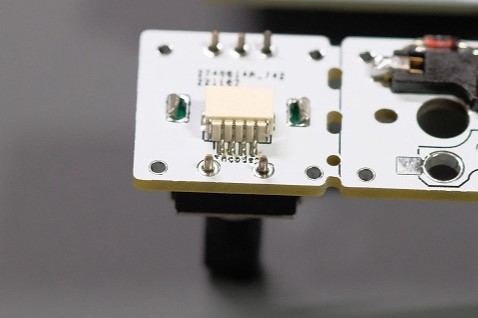
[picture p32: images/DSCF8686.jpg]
 

This completes the soldering of Main Module PCB.



### Assemble Pinky Module

Next, let's assemble Pinky Module.

[Preparation](#preparation) > [Assembly](#assembly) > [Firmware](#firmware) > [Final steps](#final-steps) > [Adjustments](#final-steps) (> [Optional Features](#optional-features) > [Further Modifications](#further-modifications))

Solder the following components as for Main Module,

* SH connector, receptacle
* Diode
* Switch socket

Make sure that eight diodes are soldered for the number of keys. If you count the number of diodes, you will not miss anything.

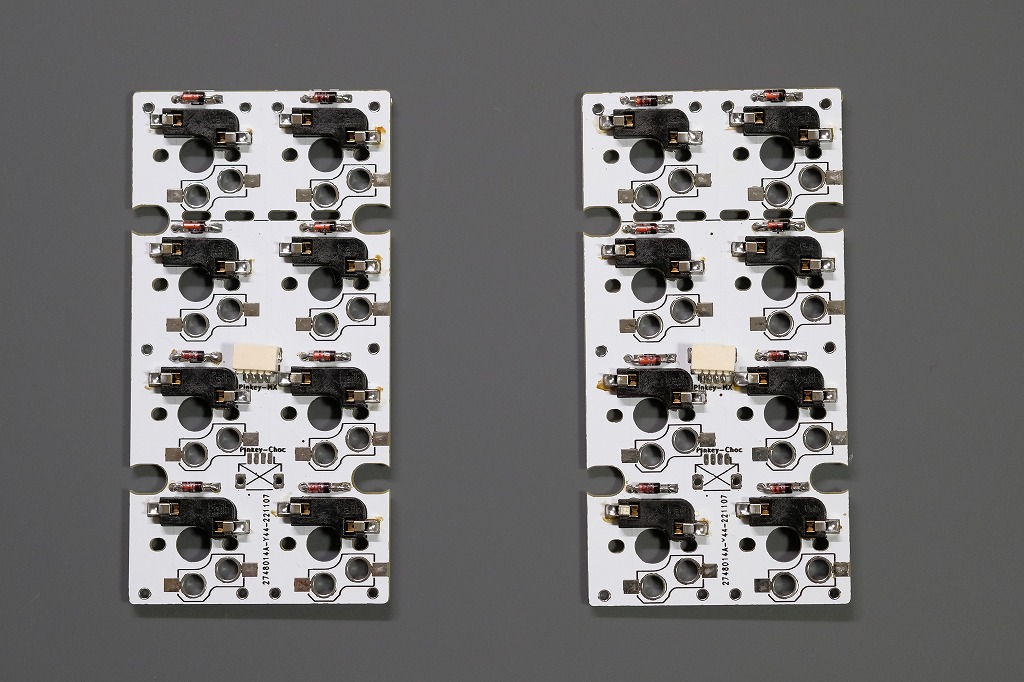
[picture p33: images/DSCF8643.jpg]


When using Cherry MX compatible switches, solder SH connectors where it says "Pinkey-MX" on the PCB.
*note: When using choc switches, solder the SH connector where it says "Pinkey-Choc" on the PCB.

### Assemble Thumb Module

Finally, let's assemble Thumb Module.

[Preparation](#preparation) > [Assembly](#assembly) > [Firmware](#firmware) > [Final steps](#final-steps) > [Adjustments](#final-steps) (> [Optional Features](#optional-features) > [Further Modifications](#further-modifications))

Solder the following components in the same manner as for Main Module and Pinky Module.

* SH connector
* Diodes
* Switch sockets

Choose one of two positions to solder the SH connector. Operation is the same regardless of which way it is soldered.
Imagine the range of motion and select the one that is easier to handle the cable.  It is recommended that the left hand side be attached at the position closer to the left when viewed from the front, and the right hand side be attached at the position closer to the right when viewed from the front.

After soldering is finished, the following picture should look like this. Check again that the diodes are oriented correctly.

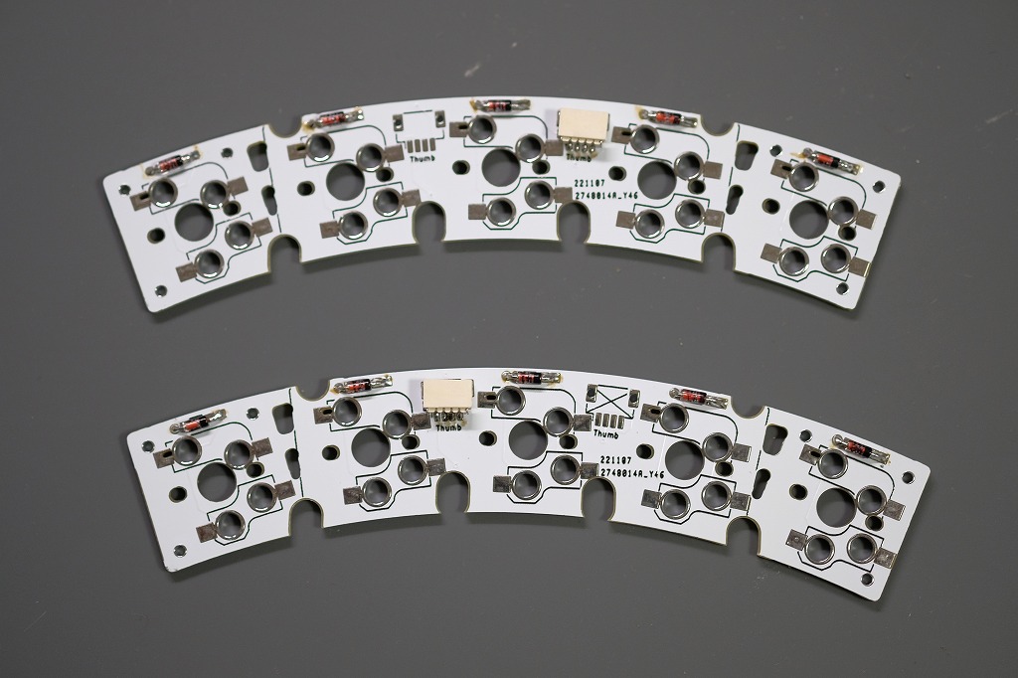
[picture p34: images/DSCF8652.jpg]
  

Now we have three PCB for Main, Pinky and Thumb.

### Install Key switches

[Preparation](#preparation) > [Assembly](#assembly) > [Firmware](#firmware) > [Final steps](#final-steps) > [Adjustments](#final-steps) (> [Optional Features](#optional-features) > [Further Modifications](#further-modifications))

Insert the key switches into the top plate of each module and secure it by inserting the legs of the keyswitch into the sockets on the PCB.
Be careful not to bend the legs of the key switch when inserting it into the socket.

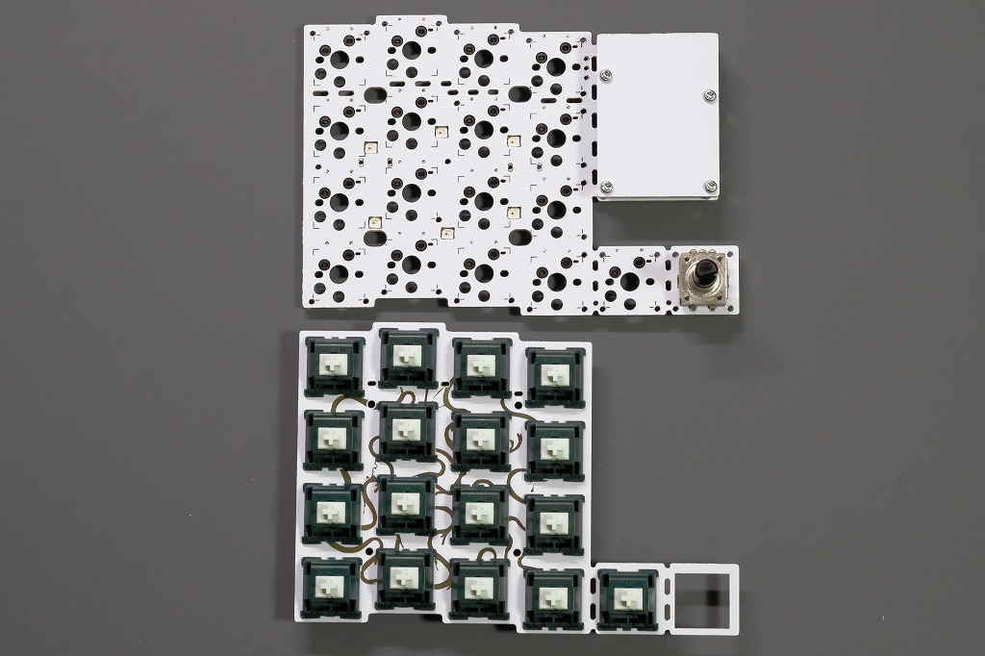
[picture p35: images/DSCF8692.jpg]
  
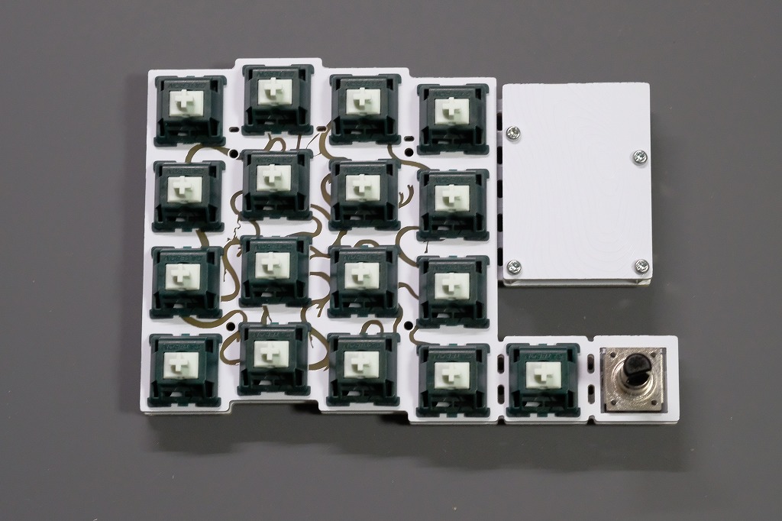
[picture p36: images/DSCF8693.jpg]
  

Observe from the backside to verify that all switch legs are in the sockets without bending.

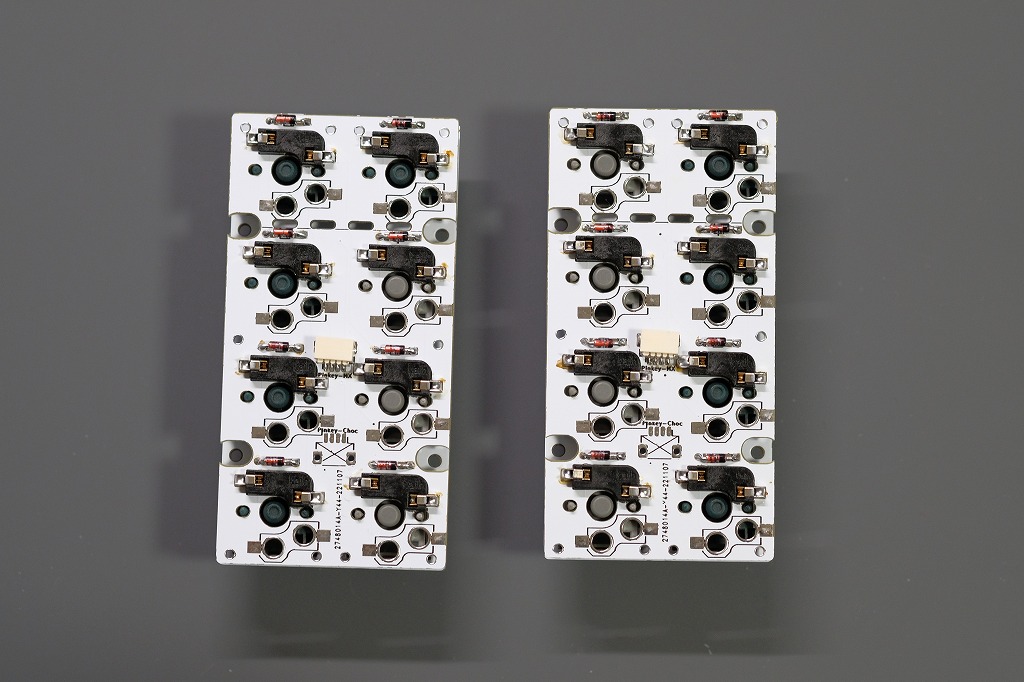
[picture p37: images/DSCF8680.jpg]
  

### Combining Modules

[Preparation](#preparation) > [Assembly](#assembly) > [Firmware](#firmware) > [Final steps](#final-steps) > [Adjustments](#final-steps) (> [Optional Features](#optional-features) > [Further Modifications](#further-modifications))

The three modules will be combined.

#### Signal connection between modules

Connect signals between plates using a cable with SH connectors.

Connect the cable to the Main Module.  If a rotary encoder is installed, also connect the cable between the rotary encoder and Main Module PCB.
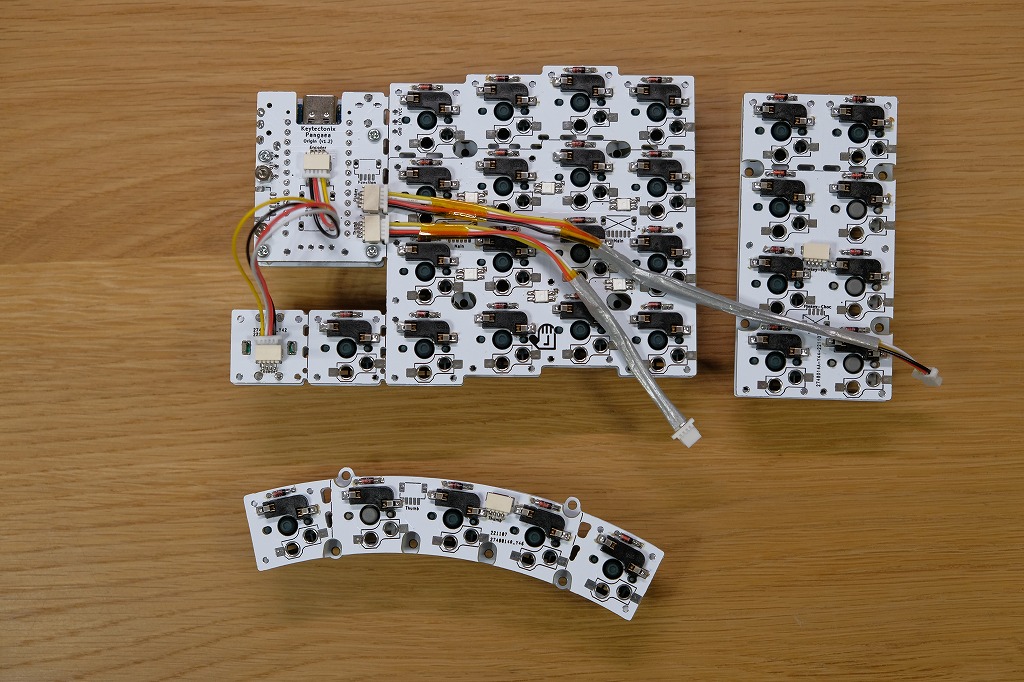
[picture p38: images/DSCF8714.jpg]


Fix the cable to the PCB with insulating tape, etc.
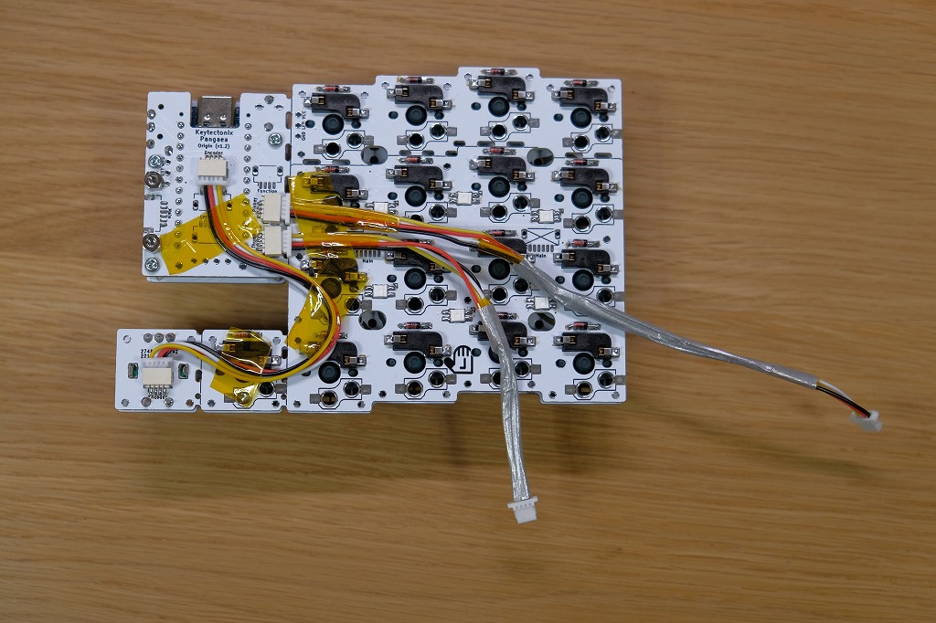
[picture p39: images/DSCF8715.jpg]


Connect the other end of the cable to Pinky and Thumb Modules.
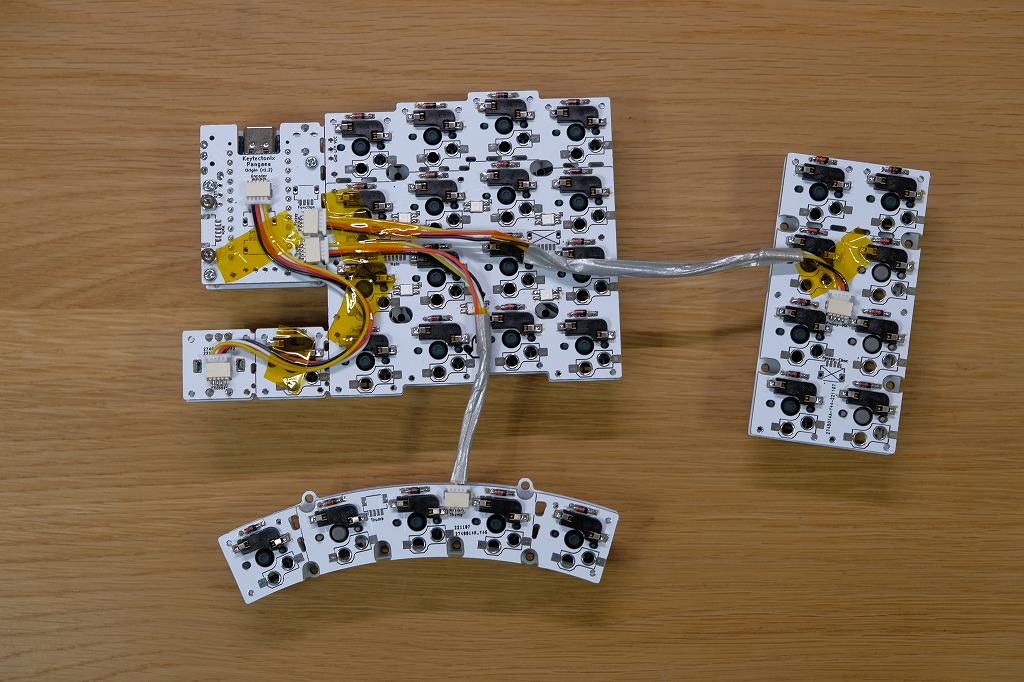
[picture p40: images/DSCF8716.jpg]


If the wire is too short, it may be pulled during adjustment, resulting in a restricted range of motion, or the wire may break. It is recommended that the wire be at least 10 cm long. If the wire is too long, it will interfere with the bottom plate.

<details>
<summary>Tips: Organize cables</summary>
<div>
If the cable does not fit well between the PCB and the bottom plate, use tape to secure the cable to the PCB before assembling the bottom plate.
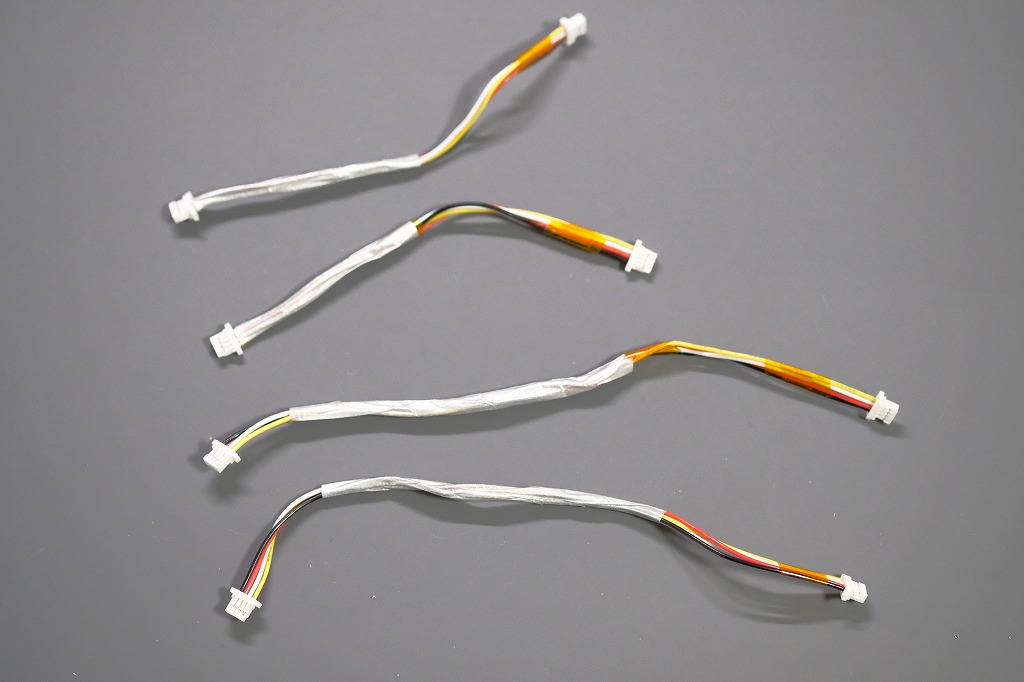
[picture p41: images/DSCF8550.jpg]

</div>
</details>

#### Coupling with Bottom Plate

Finally, the PCB and Bottom Plate are integrated. Place Main Module with switches, Thumb Module, and Pinkey Module on top of the Bottom Plate and secure them with M2 3mm screws from the top plate.

First, attach Main Module to Bottom Plate.
To make it easier to pass Bottom Plate spacers through the PCB holes, loosen the bottom plate screws slightly before overlapping them. <br/>
When they overlap without any gaps and not at an angle, insert the screws from the surface of the switch plate and tighten them. <br/>
After tightening the screws, retighten the screws on the side of the bottom plate that you loosened earlier. <br/>
There are four fixing points.

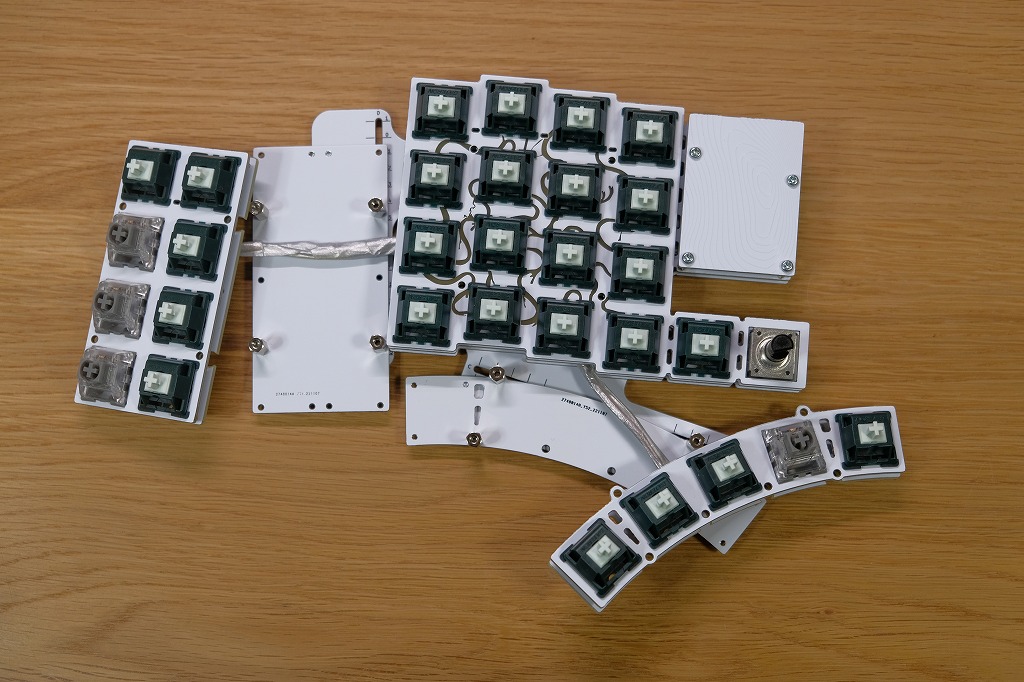
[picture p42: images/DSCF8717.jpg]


There are four fixed locations for each.

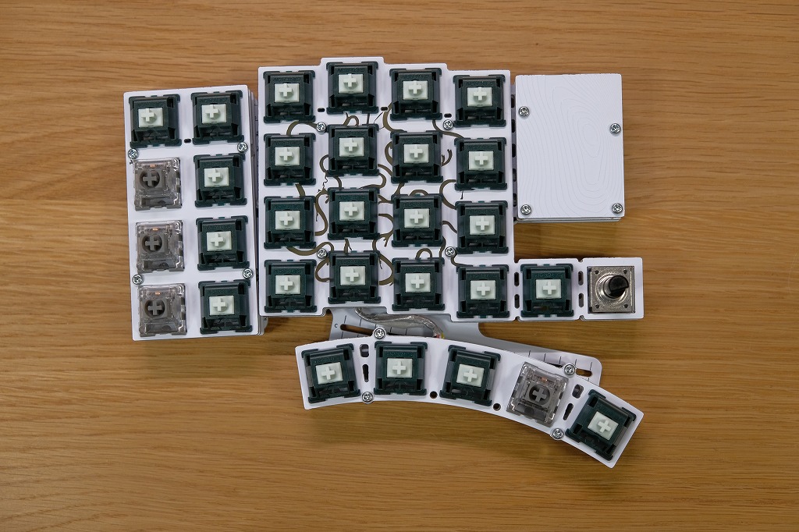
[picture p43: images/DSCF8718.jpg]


Here is a photo of the back side.

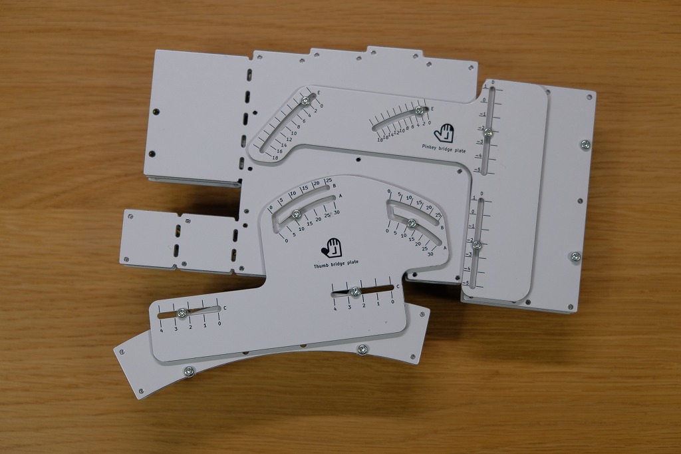
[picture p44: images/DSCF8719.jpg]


Also secure the bottom plate and the feet supporting the ProMicro with M2 3mm screws. Fix two places from the bottom of the bottom plate with M2 3mm screws.

Assemble the right hand side in the same manner.

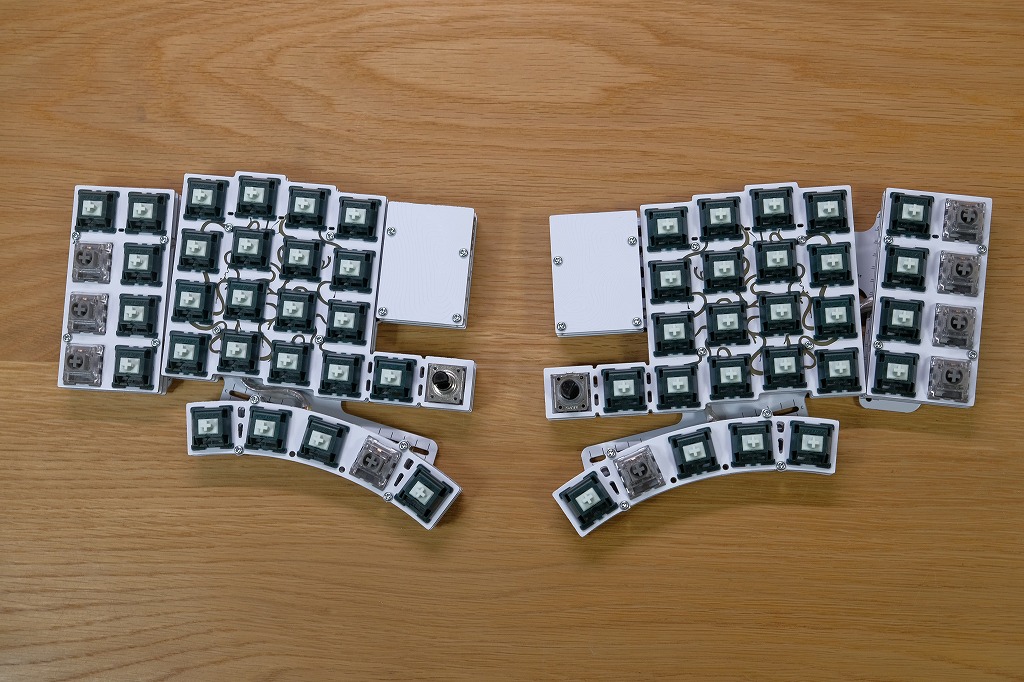
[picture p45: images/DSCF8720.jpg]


## Firmware

Write firmware into ProMicro and check operation.

[Preparation](#preparation) > [Assembly](#assembly) > [Firmware](#firmware) > [Final steps](#final-steps) > [Adjustments](#final-steps) (> [Optional Features](#optional-features) > [Further Modifications](#further-modifications))

  - [Firmware](#firmware)
    - [Flash the firmware](#flash-the-firmware)
    - [Operation check](#operation-check)

In this state, write the firmware and check the operation. If you are confident, you may skip this step and conduct it after completion.

### Flash the firmware

Flash the firmware in one of the following ways.  Download the hex from remap stie.

#### Flash the firmware using QMK Toolbox

QMK Toolbox is used here.

Open the hex file in QMK Toolbox. Connect the keyboard.

Press the reset switch to reboot the keyboard in bootloader mode.
<br/>

Since a reset switch cannot be installed on the right hand side, short the through-hole with tweezers, etc. instead of pressing the reset switch.  If it is successful and you enter bootloader mode, you will see the message "~device connected" in QMK Toolbox.

If pressing the reset switch does not put you in bootloader mode, try pressing the reset switch twice quickly.
(*note from translater: Since there is a Pro Micro that requires such operation)

Click the "Flush" button on the QML Toolbox. <br/>
Wait without unplugging the USB cable. <br/>
When the QMK Toolbox screen indicates success, the write is successful; you can unplug the USB cable.

Then write the firmware to the other Pro Micro in the same way.  There is no difference between the left and right firmware.

#### Flash the firmwarey using QMK command line tool

Go to the QMK directory, and then type

```sh
$ cd qmk_firmware
```

Flashes firmware to the ProMicro, along with compile.

```sh
$ qmk flash -kb pangaea -km default
```

### Operation check

After writing the firmware is completed, unplug the USB cable and then connect the left and right sides with the TRRS cable, and connect the USB cable only to the left side. <br/>
Do not unplug and plug the TRRS cable while the PC and keyboard are connected with the USB cable; this may short the terminals of the TRRS jack and cause the keyboard to malfunction.

Check the operation of each key on the PC.
If there is a problem such as some switches cannot be input, check the soldering carefully. If only some keys cannot be input, the possible causes include

* The diode is not installed or not soldered properly
* The diode is installed in the wrong direction
* The switch socket is installed backwards and the switch is not stuck in the first place
* The switch socket is not soldered properly, resulting in poor contact
* The leg of the switch is broken and not properly inserted into the switch socket

How could such a mistake be made? You may think so, but take a closer look.
After checking the operation, remove the USB cable and TRRS cable before returning to the rest of the assembly work.

## Final steps

Final finishing touches,

[Preparation](#preparation) > [Assembly](#assembly) > [Firmware](#firmware) > [Final steps](#final-steps) > [Adjustments](#final-steps) (> [Optional Features](#optional-features) > [Further Modifications](#further-modifications))

 * [Rubbter feet](#rubbter-feet)
 * [Keycap](#keycap)
 * [TRRS cable](#trrs-cable)

### Rubbter feet

Attach the rubber feet to the back of the bottom plate. The thickness of 3.8mm is the best size for the rubber feet without adding extra thickness to the entire keyboard.  There is no rule for the position of the rubber feet, but it is best to stick them on the four corners of the plate as shown in the photo to keep a good balance.

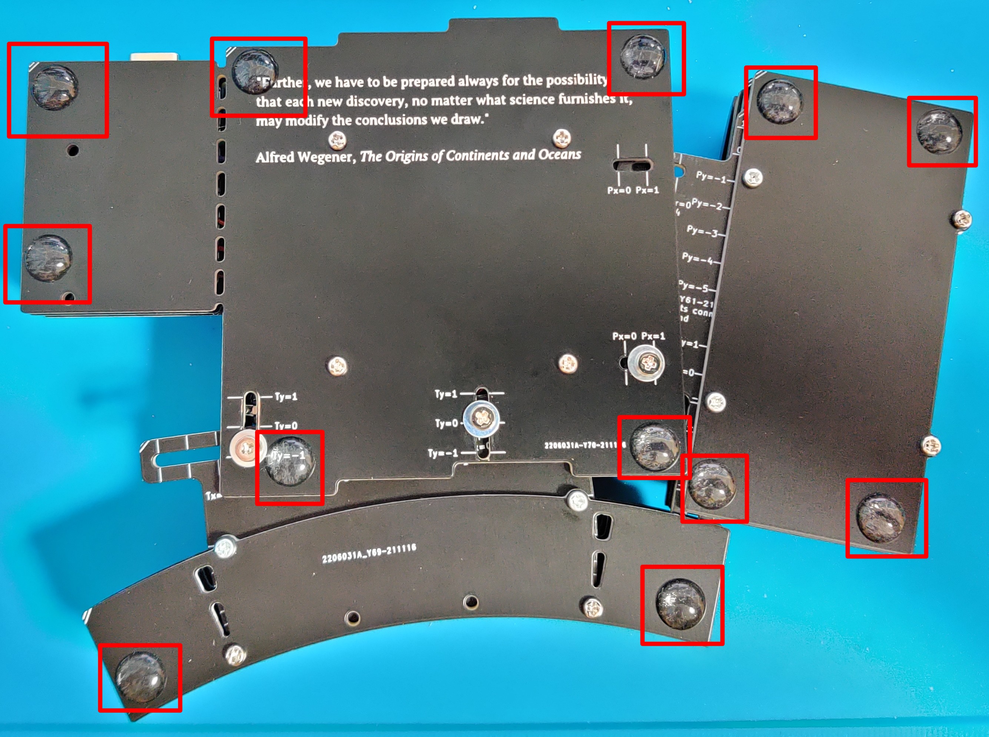
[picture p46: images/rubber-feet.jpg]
rubber-feet


While checking the range of motion, affix it in a position that does not interfere with the motion.
The following is an example for version 1.2.

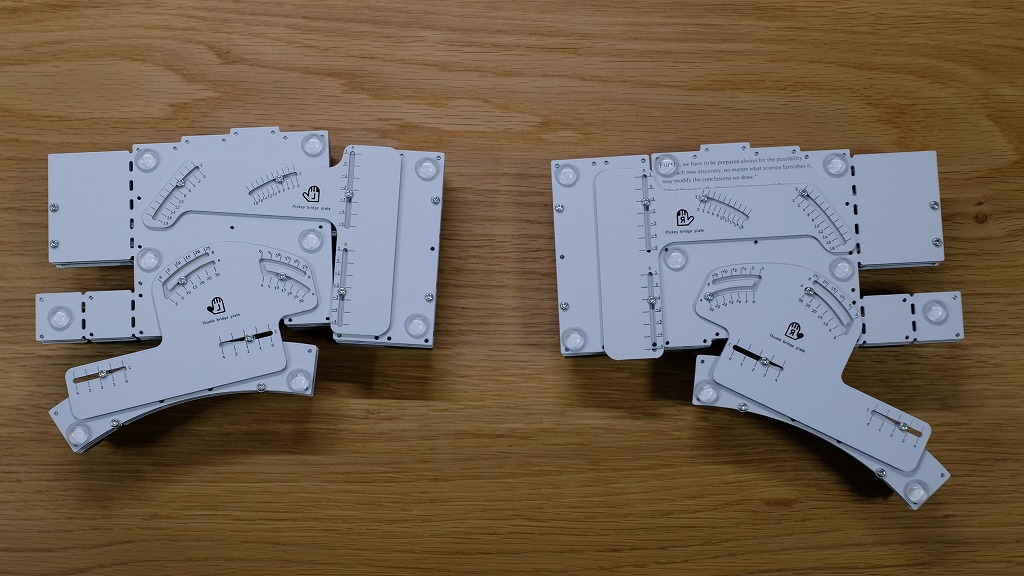
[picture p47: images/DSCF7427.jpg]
  

For additional stability, add 2.2mm-thick rubber feet to the bridge plate.  The total height of the 1.6mm-thick bridge plate and the 2.2mm-thick rubber feet is exactly the same as the 3.8mm-thick rubber feet on the bottom plate.

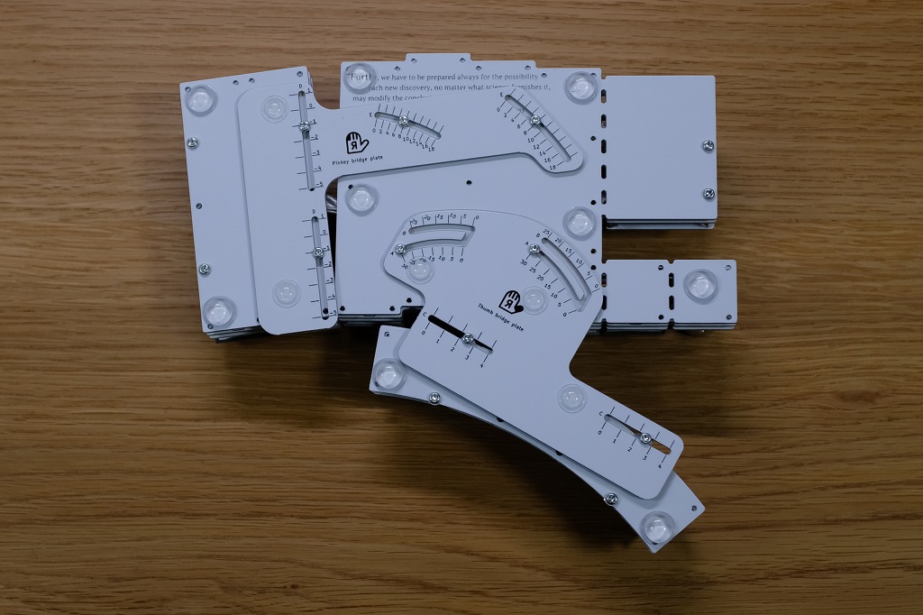
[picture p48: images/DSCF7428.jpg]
  

### Keycap

Install the key caps. If a rotary encoder is installed, install the knob as well.

### TRRS cable

Connect the left and right keyboards with the TRRS cable.

Be sure to connect the TRRS cable before connecting the keyboard and PC with the USB cable.
Also, be sure to disconnect the TRRS cable after disconnecting the keyboard from the PC.
Disconnecting and unplugging the TRRS while the keyboard and PC are connected with the USB cable may cause the TRRS terminals to short-circuit, resulting in a malfunction.

### Completed

It is completed. Good job!
Here is a shot of the Polycaps Seals when they were installed.

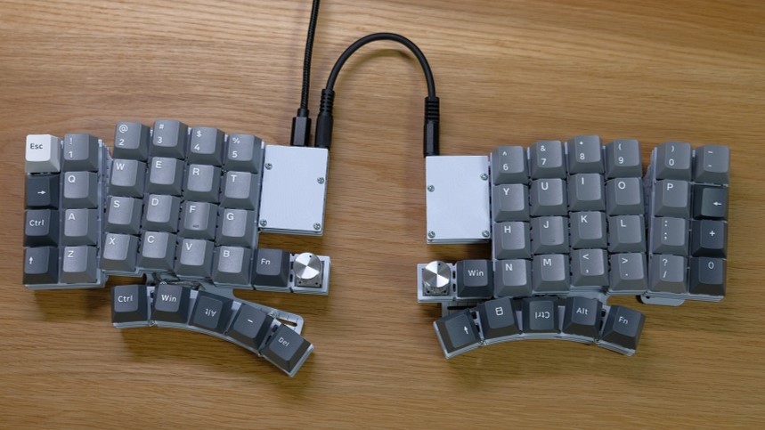
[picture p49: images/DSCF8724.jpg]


## Adjustment

Adjust the physical key layout and the software keymap.

[Preparation](#preparation) > [Assembly](#assembly) > [Firmware](#firmware) > [Final steps](#final-steps) > [Adjustments](#final-steps) (> [Optional Features](#optional-features) > [Further Modifications](#further-modifications))

* [Adjust key layout](#adjust-key-layout)
* [Changing the key map](#changing-the-key-map)

### Adjust key layout

One of the values of the Pangaea keyboard is the ability to adjust key positions.

You can find the latest firmware from [here](https://github.com/e3w2q/Pangaea-keyboard)

#### Adjustment Main Module

A length scale is provided for adjustment between the left and right main plates in the x-axis and y-axis directions.

#### Adjustment Thumb Module

The thumb module is adjustable in lateral position and rotation angle.  The adjustable range is ±0.0U to +1U for lateral position and 0° to 30° for rotation in the direction that the thumb tip side turns downward.

#### Adjustment Pinkey Module

The pinky plate can be adjusted for vertical position and rotation angle.  The adjustable range is +0.25U to -1.25U for vertical position and 0° to 18° for rotation in the direction that the upper side turns outward.

### Modifying the key map

The firmware written by the above procedure supports keymap changes by VIA and [Remap (remap-keys.app)](https://remap-keys.app/).

Please set the keymap according to the instructions of each software.
Pangaea's page in Remap's keyboard catalog is here. [Pangaea - Remap](https://remap-keys.app/catalog/t9RGwMnHCRjLxs937jxh)

## Optional features

This section describes the optional features of the standard kit.

[Preparation](#preparation) > [Assembly](#assembly) > [Firmware](#firmware) > [Final steps](#final-steps) > [Adjustments](#final-steps) (> [Optional Features](#optional-features) > [Further Modifications](#further-modifications))

* [Kailh Choc v1 switches](#kailh-choc-v1-switches)
* [Solder switches on PCB without sockets](#solder-switches-on-pcb-without-sockets)
* [Height](#height)
* [Tilts and Tents](#tilts-and-tents)
* [Tape LED](#tape-led)
* [Delete number rows](#delete-number-rows)
* [Rotary encoder](#rotary-encoder)
* [Delete rotary encoder part](#delete-rotary-encoder-part)
* [Delete the extended key](#delete-the-extended-key)
* [Seprate MPU board](#seprate-mpu-board)
* [Compatible modules](#compatible-modules)
  
### Kailh Choc v1 switches

Additional parts required: Socket for Kailh Choc v1 switch, Kailh Choc v1 switch

Compared to using Cherr MX compatible switches, the following points will change,

* Type of socket and mounting orientation
* Spacers and screw lengths to be used

### Solder switches on PCB without sockets

By pouring a large amount of solder between the keyswitch foot and the hole in the PCB, the keyswitch can be attached without using a switch socket.  Be careful not to forget to attach the switch plate.

### Height adjustment

By changing the length of the spacers, the height can be adjusted for each module.
For example, by changing the spacers, standoffs of Main Module and the Pinkey Module to longer ones, only Thumb Module can be made relatively lower.

Also, in the z-axis direction, the length of the standoffs can be made a little lower than the main plate. You can also reduce the height relative to Main plate by making only the Thumb Module using Choc switches.

### Tilts and Tents

As an application of height adjustment, the tilt and tent angle of each module can be adjusted by combining spacers of different lengths.

For example, Main plate can be height adjusted in the z-axis direction. The two standoffs in the center direction can be raised and tilted toward the center.  Be careful not to tighten the screws too hard, as this will put a load on the PCB and the plate.

### Preventing PCBs from falling out

The PCB and bottom plate have M1.4 screw holes. The PCB can be supported by inserting screws into those holes and using nuts.  Refer to the following pictures for more information.

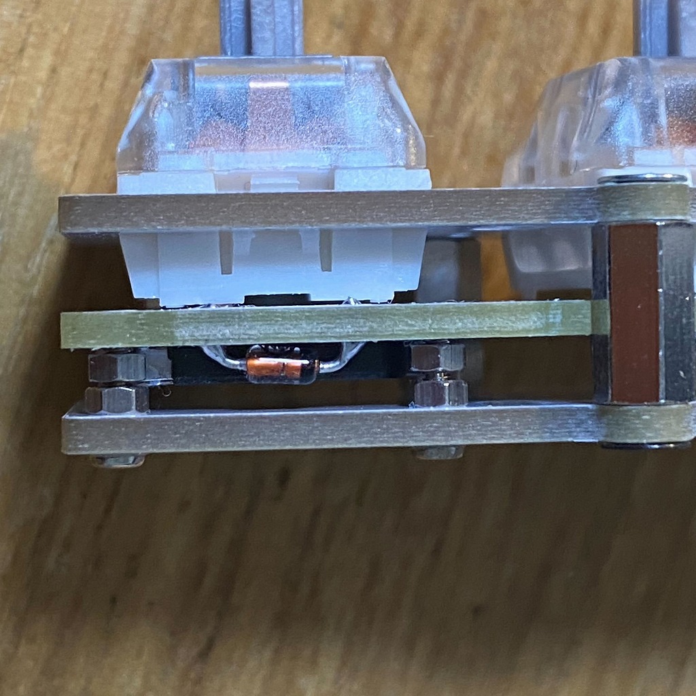
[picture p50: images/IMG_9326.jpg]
 
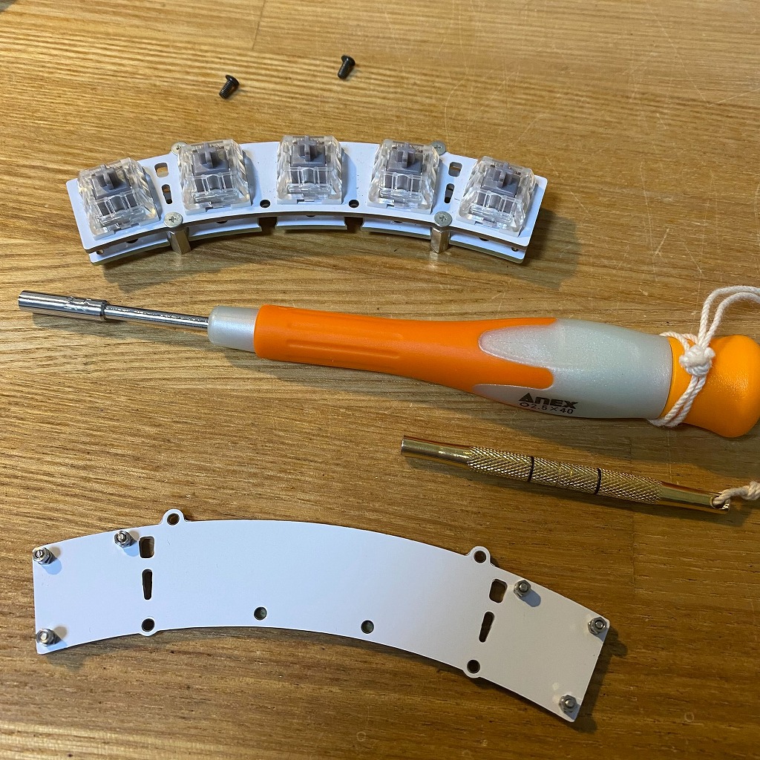
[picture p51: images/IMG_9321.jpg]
 
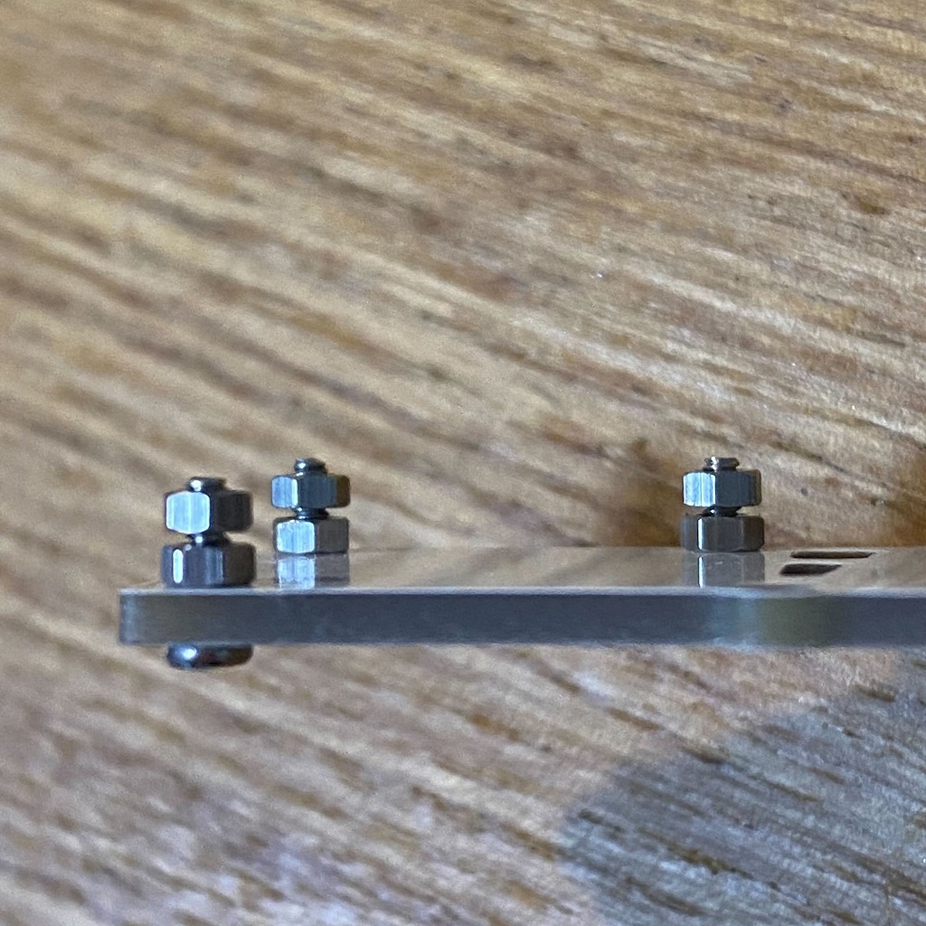
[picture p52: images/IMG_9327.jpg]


### Tape LED

Additional required components : Tape LEDs

Tape LEDs can be added; you can add tape LEDs instead of NeoPixcel or implement both NeoPixel and tape LEDs.  The standard firmware allows for six LEDs. When using tape LEDs, please cut the tape LEDs so that there are six  LEDs.

### Delete number rows

The number of keys on Main and Pineky Modules can be changed from 4 to 3 rows.
To reduce the number of rows, disconnect the switch plate and PCB.

It is not possible to undo this change, so please use your best judgment and cut carefully.

### Rotary encoder

Enable the rotary encoder: connect the back of Main Module to the rotary encoder with the SH connector cable.

### Delete rotary encoder part

The rotary encoders on the main module can be deleted.  To remove the rotary encoder, disconnect the switch plate, PCB, and bottom plate.

It is not possible to undo this change, so please use your best judgment and cut carefully.

### Delete the extended key

The extension key next to the rotary encoder on Main Module can be deleted.  To delete the extension key, disconnect the switch plate, PCB, and bottom plate.

When you delete the extension key, the rotary encoder is deleted at the same time.
If the rotary encoder is used and the expansion key is not used, do not remove the expansion key and remove the key switch only, for example.

It is not possible to undo this change, so please use your best judgment and cut carefully.

### Seprate MPU board

The Pro Micro portion of Main Module can be detached. If you want to add keys on the inside or place a trackball, for example, and this part gets in the way, you can detach it and move it to another location by wiring it to the main plate.

1. detatch the PCB
2. wiring the main plate to the Micro Pro board

### Compatible modules

Each module can be replaced with one designed to the same standard as the Pangaea keyboard, or additional modules can be added.  In the future, there will be a part with the outermost keys of the module lowered downward.  You can also design your own compatible modules.

For more information on designing compatible modules, please refer to the "Designer's Guide (currently being written)". If you have any questions, please contact the Pangaea development team.

## Further modifications

This section describes modifications using boards outside the standard kit.

[Preparation](#preparation) > [Assembly](#assembly) > [Firmware](#firmware) > [Final steps](#final-steps) > [Adjustments](#final-steps) (> [Optional Features](#optional-features) > [Further Modifications](#further-modifications))

The standard kit is sufficient for simple text input, but there will be times when you will want dedicated keys for specific applications or web conferencing.
Pangaea is freely expandable and has a standard interface for connection, making it easy to exchange parts.

As an example, we will explain how to add keys, Rotary Encoder, OLED, Joy Stick, and Dial switch.

The designer of Pangaea is e3w2q. e3w2q's famous work is SU120, which can be combined with SU120 to add Function key and Rotary Encoder.

### Adding keys

How to add a key.

1. add a key using SU120
2. support for QMK Firmware

### Adding rotary encoders

How to add a rotary encoder.

1. add a rotary encoder using SU120
2. support for QMK Firmware

### Adding displays

How to add an OLED display.

1. installation of OLED display
2. support for QMK Firmware

[Preparation](#preparation) > [Assembly](#assembly) > [Firmware](#firmware) > [Final steps](#final-steps) > [Adjustments](#final-steps) (> [Optional Features](#optional-features) > [Further Modifications](#further-modifications))

That's all.

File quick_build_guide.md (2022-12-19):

Plate and screw construction (Left hand)
Check Parts and Placement.

quick1

* Right hand is the opposite of left and right.

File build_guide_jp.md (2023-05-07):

# Pangaea Keyboard Build Guide

この文章は Pangaea Keyboard を組み立てるための手引き書です。

想定読者は自作キーボードキットを組み立てたことがある方になります。<br/>自作キーボードを組み立てたことがない方や、組み立てに自信がない方は、「Tips」を展開して確認して下さい。

Pangaea keyboard のコンセプトは [White Paper](whitepaper_jp.md) で説明されています。

ファームウェアについては [ファームウェア](#ファームウェア) の節で説明しています。QMK Firmwareのソースコードは [こちら](firmware/) です。

Pangaea Keyboardには多彩なオプション機能があり、お好みの構成を選択して組み立てることができます。  
このビルドガイドでは、標準的な構成の組み立て手順について説明します。<br/>※オプション機能については [オプション機能](#オプション機能) を参照してください。

## 目次

[Pangaea Keyboard Build Guide](#pangaea-keyboard-build-guide)

- - [準備](#準備)
    - [構造の理解](#構造の理解)
    - [構成、オプションの選択](#構成オプションの選択)
    - [必要な部品の確認](#必要な部品の確認)
  - [組み立て](#組み立て)
    - [可動ボトムプレートの組み立て](#可動ボトムプレートの組み立て)
    - [メインモジュールの組み立て](#メインモジュールの組み立て)
    - [小指モジュールの組み立て](#小指モジュールの組み立て)
    - [親指モジュールの組み立て](#親指モジュールの組み立て)
    - [キースイッチの取り付け](#キースイッチの取り付け)
    - [モジュールの合体](#モジュールの合体)
  - [ファームウェア](#ファームウェア)
    - [ファームウェアの書き込み](#ファームウェアの書き込み)
    - [動作確認](#動作確認)
  - [仕上げ](#仕上げ)
  - [調整](#調整)
    - [キー配列の調整](#キー配列の調整)
    - [キーマップの変更](#キーマップの変更)
  - [オプション機能](#オプション機能)
  - [さらなる改造](#さらなる改造)

## 準備

組み立て作業の前に準備をします。

**準備** > [組み立て](#組み立て) > [ファームウェア](#ファームウェア) > [仕上げ](#仕上げ) > [調整](#調整)  ( > [オプション機能](#オプション機能) > [さらなる改造](#さらなる改造) )

* [構造の理解](#構造の理解)
* [構成オプションの選択](#構成オプションの選択)
* [必要な部品の確認](#必要な部品の確認)

### 構造の理解

構造と用語を確認します。  
以降、キーキャップの刻印面を上にしたとき、上側を表面、下側を裏面と呼びます。

キーボードを組み立てると写真のようになります。



Pangaea Keyboard の最大の特徴は、親指プレートと小指プレートの位置を動かせることです。  
ソフトウェアでどこのスイッチに何のキーを割り当てるかだけでなく、物理的なキー配列を調整することができます。  
例えば、親指の位置を少しずらしたい、角度を少し調整して自分の指にフィットさせたい、などの調整ができるようになっています。

Pangaea Keyboardは、そのメカ的な調整機構のために部品が3つのモジュールに分かれています。

* 中央の一番大きいものがメインモジュールです
* 左右両端の縦長の長方形が小指モジュールです
* 下の円弧状のものが親指モジュールです
* 間にあるスリットの空いたプレートは、ブリッジプレートと呼びます
* さらに、モジュール間で電気信号を伝えるためケーブルで接続します



### 構成、オプションの選択

Pangaea keyboardには様々なオプション機能があります。  
このビルドガイドでは、標準的な構成の組み立て手順を説明します。  
※オプション機能については [オプション機能](#オプション機能) を参照してください。

このビルドガイドで説明する標準構成は次の通りです。

* [x] MX互換スイッチを使用
* [x] スイッチソケットを使用
* [x] スルーホールダイオードを使用
* [x] LEDを実装（省略可）
* [x] ロータリーエンコーダーあり（省略可）
* [x] ProMicroをピンヘッダでPCBに直接はんだ付けして固定する
* [x] 縦向きの（普通の）リセットスイッチを使用する
* [x] ビルド済みのVIA対応ファームウェアを使用する
* [x] 親指キーは左右5個ずつ
* [x] 数字行、ロータリーエンコーダー、拡張キー、ProMicro部分を切り離さない
* [x] その他、追加の改造を行わない

標準構成と異なるオプションを選択した場合は、組み立て手順を読み替えて作業を進めてください。

### 必要な部品の確認

| 種類 | 数量  | 備考 |
| --- | ----- | --- |
| --- **基板類** --- | | |
| メインモジュールPCB左手側 | 1 | |
| メインモジュールPCB右手側 | 1 | |
| メインモジュールProMicroカバープレート | 2 | 左右共通 |
| メインモジュールスイッチプレート | 2 | 左右共通 |
| メインモジュールボトムプレート | 2 | 左右共通 |
| 小指モジュールPCB | 2 | 左右共通 |
| 小指モジュールスイッチプレート | 2 | 左右共通 |
| 小指モジュールボトムプレート | 2 | 左右共通 |
| 親指モジュールPCB | 2 | 左右共通 |
| 親指モジュールスイッチプレート | 2 | 左右共通 |
| 親指モジュールボトムプレート | 2 | 左右共通 |
| 小指ブリッジプレート | 2 | 左右共通 |
| 親指ブリッジプレート | 2 | 左右共通 |
| --- **電子部品類**--- | | |
| ProMicroまたは互換ボード | 2 | ATmega32U4, 5V |
| ピンヘッダー | 4 | ProMicor付属の物 |
| タクトスイッチ | 1* | 左手側用。*省略可<br />（右手側はリセットスイッチを取り付けることができません。） |
| 3.5mm TRRSジャック | 2 | |
| ダイオード | 60 | |
| スイッチソケット | 60 | |
| MX互換キースイッチ | 60 | |
| LED NeoPixel SK6812MINI-E | 12* | *省略可 |
| ロータリーエンコーダー | 2* | *省略可 |
| JST SH 4pinクロスケーブル長さ10cm | 2* | メイン-ロータリーエンコーダー間接続用。*省略可 |
| JST SH 4pinクロスケーブル長さ10cm | 2 | メイン-小指モジュール間接続用 |
| JST SH 4pinクロスケーブル長さ15cm | 2 | メイン-親指モジュール間接続用 |
| JST SH 4pinコネクターレセプタクル表面実装サイドタイプ | 8 | |
| --- **ネジ類** --- | | |
| M2両ネジ六角スペーサー長さ8mm | 24 | スイッチプレートの支持用。片手12個 |
| M2両ネジスペーサー長さ3mm | 4 | ProMicro周りのPCB支持用。片手2個 |
| M2両ネジスペーサー長さ6mm | 8 | ProMicroカバーの支持用。片手4個 |
| M2ネジ長さ8mm | 24 | ボトムプレートの固定。片手12本 |
| M2ネジ長さ3mm | 48 | スイッチプレートの固定、PCB支持、ProMicroカバー固定。片手24個 |
| --- **小物類** --- | | |
| USBケーブル | 1 | Pro Micro互換ボードとPCを繋ぐ。 |
| TRRSケーブル | 1 | 左右のメインモジュールを繋ぐ。 |
| キーキャップ | 60 | すべて1Uサイズ。 |
| ロータリーエンコーダーのノブ | 2* | 直径19mmまで。*省略可 |
| ゴム足 2.2mm厚 | 約10* | ブリッジプレートに貼る。*省略可 |
| ゴム足 3.8mm厚 | 約20  | ボトムプレートに貼る |
| マスキングテープ | 少々* | ケーブルをまとめるのに使用。*省略可 |
| 絶縁テープ | 少々* | ケーブルをPCBに固定して引き回しやすくする。*省略可 |

各部品の詳細な型番や入手先は[パーツリスト（BOM）](bom_list_jp.md)を参照してください。

SHケーブルは、両端のピンアサインが変わらないタイプを使用してください。

sh-cable

オプションの選択によって、必要な部品の種類や数が変わることがあります。
※オプション機能については [オプション機能](#オプション機能) を参照してください。

基板類をすべて並べた写真がこちらです。不足がないことを確認してください。

all-parts

* メインモジュールPCBは、左右で部品が異なります。
* 小指モジュールと親指モジュールは、右手側と左手側で同じ物を使用します。
* メインモジュールスイッチプレート、メインモジュールボトムプレート、ブリッジプレートは、左右同じものを使用しますが、使用する向きが異なります
  * **裏面**から見たときにLマークが見えるほうが左手側、**裏面**から見たときにRマークが見えるほうが右手側になる向きで使用します。

## 組み立て

[準備](#準備) > **組み立て** > [ファームウェア](#ファームウェア) > [仕上げ](#仕上げ) > [調整](#調整)  ( > [オプション機能](#オプション機能) > [さらなる改造](#さらなる改造) )

* [可動ボトムプレートの組み立て](#可動ボトムプレートの組み立て)
* [メインモジュールの組み立て](#メインモジュールの組み立て)
* [小指モジュールの組み立て](#小指モジュールの組み立て)
* [親指モジュールの組み立て](#親指モジュールの組み立て)
* [キースイッチの取り付け](#キースイッチの取り付け)
* [モジュールの合体](#モジュールの合体)

組み立ての順番を間違えても取り返しがつかないようなことにはなりません。気楽に進めてください。

###  可動ボトムプレートの組み立て

最初に可動ボトムプレートを組み立てます。Pangaea Keyboardの醍醐味である可変機構をぜひ味わって下さい。

8mmのネジと8mmのスペーサーを赤丸の位置に取り付けます。裏側からネジ頭、ブリッジプレート、ボトムプレート、スペーサーの順で重ねます。

完成形は以下の写真のようになります。メインモジュールに対して、小指モジュール、親指モジュールが自由に調整できる機構が組み込まれています。  



裏から見ると下の写真のようになっています。



<details>
<summary>Tips: ワッシャーの追加</summary>
<div>
組み立て後の稼働をよりスムーズにするため、可動部分にはワッシャーとスプリングワッシャーを使うことをおすすめします。直接ネジ止めするとネジが緩みやすく、調整のためにドライバーでネジ止めすることになり不便に感じられると思います。ワッシャーとスプリングワッシャーを使うことで、ある程度きつくネジを締めた状態でも可動できるようになるため、組み立て後の調整が楽になります。
</div>
</details>

※組み立てに使用するネジとスペーサーの長さは、下図のようになります。

screw

### メインモジュールの組み立て

メインモジュールから順に、各モジュールのPCBに部品を取り付けていきます。

[準備](#準備) > **組み立て** > [ファームウェア](#ファームウェア) > [仕上げ](#仕上げ) > [調整](#調整)  ( > [オプション機能](#オプション機能) > [さらなる改造](#さらなる改造) )

組み立て > [可動ボトムプレートの組み立て](#可動ボトムプレートの組み立て) > **メインモジュールの組み立て** > [小指モジュールの組み立て](#小指モジュールの組み立て) > [親指モジュールの組み立て](#親指モジュールの組み立て) > [キースイッチの取り付け](#キースイッチの取り付け) > [モジュールの合体](#モジュールの合体)

メインモジュールには、以下の部品を取り付けます。組み立てやすい順番で記載しています。

- [LED（オプション）](#LED（オプション）)
- [SHコネクタレセプタクル](#SHコネクタレセプタクル)
- [ダイオード](#ダイオード)
- [スイッチソケット](#スイッチソケット)
- [ProMicro](#ProMicro)
- [TRRSジャック](#TRRSジャック)
- [リセットスイッチ（オプション）](#リセットスイッチ（オプション）)

#### LED（オプション）

LEDをPCBの**裏**面にはんだ付けします。LEDは<u>光る面が表側</u>を向きます。
マイコン内蔵LEDは高温に弱いため、はんだごての温度を下げます。250℃以下にすることをおすすめします。

LEDは取り付ける向きが決まっています。
LEDの端子が斜めにカットされている足をPCBの三角形のマークに合わせます。（赤線部分）

 

#### SHコネクタレセプタクル

SHコネクタのレセプタクルをPCBの**裏**面にはんだ付けします。やや難しいので慎重に行います。
小指モジュール用、親指モジュール用のコネクタをそれぞれ取り付けます。

ロータリーエンコーダーを使用する場合は、ロータリーエンコーダー用のSHコネクタもはんだ付けします。

 

裏側からスルーホールにはんだを流し込み、SHコネクタの両端にある固定足をはんだ付けします。



#### ダイオード

ダイオードをPCBの**裏**面にはんだ付けします。

ダイオードの方向は、PCB上の白い線（PCBが白地の場合は黒い線）と、ダイオードの黒い線を合わせます。

 

表面実装向けの Surface Mount Device(SMD) のダイオードを利用する場合は、SMD の ダイオードの線とPCB の線の位置を合わせます。写真の例では、T4と書かれた左の線とPCBの線を合わせます。

  

左手用のメインモジュールPCBを裏から見た状態です。これから左を先に実装します。

#### スイッチソケット

スイッチソケットも同様にPCBの**裏**側にはんだ付けします。

MX互換スイッチを用いる場合は上側にソケットを取り付けます。



#### Reset switchの取り付け

PCBの**表**側からはんだ付けします。

右手側はリセットスイッチを取り付けることができません。（リセットする際は、リセットスイッチを押す代わりにピンセット等でスルーホールをショートしてください。）

#### 3.5mm TRRSジャックの取り付け

PCBの**表**側からはんだ付けします。

#### Pro Microの取り付け

ProMicroをメインプレートPCBの**表側**に取り付けます。ProMicroの向きは実装面を下にします。つまり、ProMicroのつるつるの面が上を向き、ProMicroの色々部品がついている面は隠れる向きです。

※ コンスルーを使用する場合は、「ProMicro コンスルー 」で検索してみてください。遊舎工房の資料が分かりやすいです。[コンスルー（スプリングピンヘッダ）の取り付け方を教えて下さい – 遊舎工房サポートサイト (zendesk.com)](https://yushakobo.zendesk.com/hc/ja/articles/360044233974-コンスルー-スプリングピンヘッダ-の取り付け方を教えて下さい)

まず、ProMicro付属のピンヘッダーをPCBに差し込みます。短いほうを上にして、長いほうを差し込みます。



裏側はこのように飛び出します。



次に、ProMicroを上から重ねます。



ProMicroとピンヘッダーをはんだ付けします。隣り合ったピンとはんだがブリッジしないよう注意してください。



そして、裏側に飛び出したピンヘッダーをニッパーで短く切り、PangaeaのPCBとピンヘッダーをはんだ付けします。





※ピンヘッダーを切るときは、切れ端が飛ばないよう十分注意してください。

#### ProMicroを支える足をねじ止めする

M2 3mmのネジとM2 3mmのスペーサーを水色丸の位置に取り付けます。これはPCBのProMicro周辺部を支えるためのスペーサーです。後の工程でボトムプレートに接続されます。

 

裏から見ると下図のようになります。



#### ProMicroカバーの取り付け

M2 3mmのネジとM2 6mmスペーサーをPCBの**表側**に取り付けます。PCBの裏側からM2 3mmのネジを入れて固定してください。

Pro Microの上にカバープレートを重ねて、4箇所をM2 3mmのネジで固定します。
プレートには裏表がありますで、スペーサーと穴が重なる向きで取り付けてください。

#### ロータリーエンコーダーのはんだ付け（オプション）

ロータリーエンコーダーをはんだ付けします。
プッシュスイッチ付きの場合は、スイッチの端子もはんだ付けします。

 

これでメインモジュールPCBのはんだ付けが完了しました。



### 小指モジュールの組み立て

続いて、小指モジュールの組み立てです。

[準備](#準備) > **組み立て** > [ファームウェア](#ファームウェア) > [仕上げ](#仕上げ) > [調整](#調整)  ( > [オプション機能](#オプション機能) > [さらなる改造](#さらなる改造) )

組み立て > [可動ボトムプレートの組み立て](#可動ボトムプレートの組み立て) > [メインモジュールの組み立て](#メインモジュールの組み立て) > **小指モジュールの組み立て** > [親指モジュールの組み立て](#親指モジュールの組み立て) > [キースイッチの取り付け](#キースイッチの取り付け) > [モジュールの合体](#モジュールの合体)

メインモジュールと同様に、以下の部品をはんだ付けします。

- SHコネクタレセプタクル
- ダイオード
- スイッチソケット

キーの個数分の8個のダイオードが取り付けられているか確認します。個数を数えれば見逃しがないと思います。



MX互換スイッチを用いる場合は、PCBに「Pinkey-MX」と書いてある場所にSHコネクタを取り付けます。

※chocスイッチを用いる場合は、「Pinkey-Choc」と書いてある場所にSHコネクタを取り付けてください。

### 親指モジュールの組み立て

最後に親指モジュールを組み立てます。

[準備](#準備) > **組み立て** > [ファームウェア](#ファームウェア) > [仕上げ](#仕上げ) > [調整](#調整)  ( > [オプション機能](#オプション機能) > [さらなる改造](#さらなる改造) )

組み立て > [可動ボトムプレートの組み立て](#可動ボトムプレートの組み立て) > [メインモジュールの組み立て](#メインモジュールの組み立て) > [小指モジュールの組み立て](#小指モジュールの組み立て) > **親指モジュールの組み立て** > [キースイッチの取り付け](#キースイッチの取り付け) > [モジュールの合体](#モジュールの合体)

メインモジュール、小指モジュールと同様に、以下の部品をはんだ付けします。

- SHコネクタ
- ダイオード
- スイッチソケット

SHコネクタの取り付け位置は2箇所から1つを選択します。どちらに接続しても動作は同じです。
可動範囲をイメージして、ケーブルの取り回しがしやすい方を選択してください。
左手側は表から見て左寄りの位置、右手側は表から見て右寄りの位置にそれぞれ取り付けるのがおすすめです。

はんだ付けが終わると、次の写真のようになります。ダイオードの方向に間違いがないか再度確認してください。

  

以上で、メイン・小指・親指の三つのPCBプレートが用意できました。

### キースイッチの取り付け

[準備](#準備) > **組み立て** > [ファームウェア](#ファームウェア) > [仕上げ](#仕上げ) > [調整](#調整)  ( > [オプション機能](#オプション機能) > [さらなる改造](#さらなる改造) )

 組み立て > [可動ボトムプレートの組み立て](#可動ボトムプレートの組み立て) > [メインモジュールの組み立て](#メインモジュールの組み立て) > [小指モジュールの組み立て](#小指モジュールの組み立て) > [親指モジュールの組み立て](#親指モジュールの組み立て) > **キースイッチの取り付け** > [モジュールの合体](#モジュールの合体)

各モジュールのトッププレートにキースイッチを挿入し、キースイッチの足をPCBのソケットに挿しこんで固定します。
ソケットに挿しこむ際にキースイッチの足が曲がらないよう、注意してください。

  
  

すべてのスイッチの足が曲がらずにソケットに入っていることを、裏側から観察して確認します。

  

### モジュールの合体

モジュールを合体していきます。

[準備](#準備) > **組み立て** > [ファームウェア](#ファームウェア) > [仕上げ](#仕上げ) > [調整](#調整)  ( > [オプション機能](#オプション機能) > [さらなる改造](#さらなる改造) )

 組み立て > [可動ボトムプレートの組み立て](#可動ボトムプレートの組み立て) > [メインモジュールの組み立て](#メインモジュールの組み立て) > [小指モジュールの組み立て](#小指モジュールの組み立て) > [親指モジュールの組み立て](#親指モジュールの組み立て) > [キースイッチの取り付け](#キースイッチの取り付け) > **モジュールの合体**

#### モジュール間の信号接続

プレート同士の信号をSHコネクタを用いて接続します。

メインモジュールにケーブルコネクタを接続します。
ロータリーエンコーダーを取り付けた場合は、ロータリーエンコーダーとProMicroを接続します。

ケーブルを絶縁テープ等でPCBに固定します。

ケーブルの反対側を小指モジュール、親指モジュールに接続します。


あまりワイヤが短いと調整の時に引っ張ってしまって可動域に制約が出たり、ワイヤが切れたりします。少なくとも10cm程度の長さを確保したほうがよいです。余り長くても邪魔になりますのでボトムプレートと組み合わせて確認してみるとよいと思います。

<details>
<summary>Tips: ケーブルの整理</summary>
<div>
ケーブルがPCBとボトムプレートの間にうまく収まらない場合は、テープでケーブルをPCBに固定してからボトムプレートを組み立ててください。

</div>
</details>

#### ボトムプレートとの結合

いよいよ、PCBとボトムプレートを統合していきます。スイッチがついたメインモジュール、親指モジュール、小指モジュールをボトムプレートの上に乗せてトッププレートの上からM2 3mmネジで固定します。

まず、メインモジュールをボトムプレートに取り付けます。

ボトムプレートのスペーサーをPCBの穴に通しやすくするため、ボトムプレートのネジを少し緩めてから重ねます。<br/>
斜めにならず隙間なく重なったらスイッチプレートの表面からネジを入れて締めます。<br/>
ネジを締めたら、先ほど緩めたボトムプレートの側のネジを締めなおします。<br/>
固定箇所は4箇所です。



小指モジュール、親指モジュールも同様にM2 3mmのネジで固定します。<br/>
固定箇所はそれぞれ4箇所です。



裏側です。



また、ボトムプレートとProMicroを支える足もM2 3mmのネジで固定します。ボトムプレートの下からM2 3mmのネジで2箇所を固定します。

右手側も同様に結合します。



## ファームウェア

ファームウェアを書き込み、動作確認をします。

[準備](#準備) > [組み立て](#組み立て) > **ファームウェア** > [仕上げ](#仕上げ) > [調整](#調整) ( > [オプション機能](#オプション機能) > [さらなる改造](#さらなる改造))

* [ファームウェアの書き込み](#ファームウェアの書き込み)
  * [QMK Toolboxを使って書き込む](#QMK Toolboxを使って書き込む)
  * [QMKコマンドを使って書き込む](#QMKコマンドを使って書き込む)

* [動作確認](#動作確認)

この状態でファームウェアを書き込んで動作を確認します。自信がある方はここをスキップして、完成してから実施しても構いません。

### ファームウェアの書き込み

下記いずれかの方法でファームウェアを書き込みます。

hexはremapからダウンロードしてください。

#### QMK Toolboxを使って書き込む

QMK Toolboxを使います。

QMK Toolboxでhexファイルを開きます。
キーボードを接続します。

リセットスイッチを押して、キーボードをブートローダーモードで再起動します。<br/>

右手側はリセットスイッチを取り付けることができませんので、リセットスイッチを押す代わりにピンセット等でスルーホールをショートしてください。
成功してブートローダモードに入ると、QMK Toolboxに「～device connected」というメッセージが表示されます。

もしリセットスイッチを押してもブートローダモードにならない場合は、リセットスイッチを素早く2回押してみてください。

QML Toolboxの「Flush」ボタンをクリックします。<br/>
USBケーブルを抜かずに待機します。<br/>
QMK Toolboxの画面に成功の旨が表示されたら、書き込み成功です。USBケーブルを抜くことができます。

続いて、もう一つのPro Microにも同じ方法でファームウェアを書き込みます。
左右でファームウェアの違いはありません。

#### QMKコマンドを使って書き込む

QMK の directory に移動してから、

```sh
cd qmk_firmware
```

ProMicro に firmware を書き込みます。Compileも一緒に行います。

```sh
qmk flash -kb pangaea -km default
```

### 動作確認

ファームウェアの書き込みが完了したら、USBケーブルを抜いてから左右をTRRSケーブルで接続し、左側にだけUSBケーブルを接続します。<br/>
PCとキーボードをUSBケーブルで接続した状態でTRRSケーブルを抜き差ししないでください。TRRSジャックの端子がショートして、キーボードが故障する可能性があります。

PCで各キーの動作を確認します。

一部のスイッチが入力できないなど問題があればハンダ付けをよく確認してください。一部のキーだけが入力できない場合、原因として下記のようなことが考えられます。

- ダイオードが取り付けられていない
- ダイオードの方向が逆に取り付けられている
- スイッチソケットを逆に取り付けていて、そもそもスイッチが刺さっていない
- スイッチソケットのハンダ付けが不十分で、接触不良
- スイッチの足が折れていて、正常にスイッチソケットに刺さっていない

そんなミスするわけない！と思うかもしれませんが、よく見てみましょう。

動作確認が終わったら、USBケーブルとTRRSケーブルを取り外してから、残りの組み立て作業に戻ります。

## 仕上げ

最後の仕上げをします。

[準備](#準備) > [組み立て](#組み立て) > [ファームウェア](#ファームウェア) > **仕上げ** > [調整](#調整)  ( > [オプション機能](#オプション機能) > [さらなる改造](#さらなる改造) )

* [ゴム足の取り付け](#ゴム足の取り付け)
* [キーキャップの取り付け](#キーキャップの取り付け)
* [TRRSケーブルの接続](#trrsケーブルの接続)

### ゴム足の取り付け

ボトムプレートの裏側にゴム足を貼り付けます。ゴム足の厚さは3.8mmがキーボード全体に余計な厚みが出ないベストなサイズです。

ゴム足の位置に決まりはありませんが、写真のようにプレートの四隅を支えるように貼り付けるとバランスが取れて良いでしょう。

可動範囲を確認しながら、可動の邪魔にならない位置に貼り付けてください。
以下は、v.1.2の例です。

  

さらなる安定を求める場合は、ブリッジプレートに2.2mm厚のゴム足を追加してください。
1.6mm厚のブリッジプレートと2.2mm厚のゴム足を合計した高さが、ちょうどボトムプレートの3.8mm厚のゴム足と同じ高さになります。

  

### キーキャップの取り付け

キーキャップをはめます。ロータリーエンコーダーを取り付けた場合はノブもはめます。

### TRRSケーブルの接続

左右のキーボードをTRRSケーブルで接続します。

必ずキーボードとPCをUSBケーブルで接続する前にTRRSケーブルを接続してください。
また、必ずキーボードとPCの接続を外してからTRRSケーブルを抜くようにしてください。
キーボードとPCをUSBケーブルで接続したままTRRSの抜き差しをすると、TRRS端子がショートして故障の原因になる可能性があります。

### 完成！

完成です。お疲れ様でした！



## 調整

物理的なキー配列と、ソフトウェア的なキーマップを調整します。

[準備](#準備) > [組み立て](#組み立て) > [ファームウェア](#ファームウェア) > [仕上げ](#仕上げ) > **調整**  ( > [オプション機能](#オプション機能) > [さらなる改造](#さらなる改造))

* [キー配列の調整](#キー配列の調整)
* [キーマップの変更](#キーマップの変更)

### キー配列の調整

Pangaea keyboard の価値の一つは位置を調整できることです。好きなように調整してください、なのですが、自由度が高すぎても困ると思いますので私の例で説明します。

私の調整した結果を例として写真を掲載します。

#### メインモジュールの調整

またx軸、y軸方向の調整として左右のメインプレート間の調整用にscaleが用意されています。ある程度固定次第長さに切って使用するとよいでしょう。

- 左右の間隔調整
- 左右の角度調整

#### 親指モジュールの調整

親指モジュールは、横方向の位置と回転角度を調整できます。

調整可能範囲は、横位置は±0.0U～+1U、回転は親指先側が下に回る方向に0°～30°です。

#### 小指モジュールの調整

小指プレートは、縦方向の位置と回転角度を調整できます。

調整可能範囲は、縦位置は+0.25U～-1.25U、回転は上側が外に回る方向に0°〜18°です。

#### 調整例

親指：回転13°、左右シフト0<br />
小指：回転5.5°、上下シフト-1.8

### キーマップの変更

上記手順で書き込んだファームウェアは、VIAおよび[Remap (remap-keys.app)](https://remap-keys.app/)によるキーマップ変更に対応しています。

各ソフトの説明にしたがってキーマップを設定してください。

RemapのキーボードカタログにおけるPangaeaのページはこちらです。[Pangaea - Remap](https://remap-keys.app/catalog/t9RGwMnHCRjLxs937jxh)

## オプション機能

標準キットのオプション機能を説明します。

[準備](#準備) > [組み立て](#組み立て) > [ファームウェア](#ファームウェア) > [仕上げ](#仕上げ) > [調整](#調整)  ( > **オプション機能** > [さらなる改造](#さらなる改造))

* [Kailh Choc v1スイッチの使用](#Kailh-Choc-v1スイッチの使用)
* [スイッチソケットを使用せずキースイッチを直接PCBにはんだ付けする](#スイッチソケットを使用せずキースイッチを直接PCBにはんだ付けする)
* [高さの調整](#高さの調整)
* [チルトとテント](#チルトとテント)
* [PCBの脱落防止](#PCBの脱落防止)
* [テープLEDの追加](#テープledの追加)
* [数字行の削除](#数字行の削除)
* [ロータリーエンコーダーの実装](#ロータリーエンコーダーの実装)
* [ロータリーエンコーダーの削除](#ロータリーエンコーダーの削除)
* [拡張キーの削除](#拡張キーの削除)
* [マイコンボード周辺部分の切り離し](#マイコンボード周辺部分の切り離し)
* [互換モジュールの使用](#互換モジュールの使用)

### Kailh Choc v1スイッチの使用

追加で必要な部品：Kailh Choc v1スイッチ用ソケット、Kailh Choc v1スイッチ

MX互換スイッチを使用する場合と比べて、次の点が変わります。

* ソケットの種類、取り付け向き

* 使用するスペーサー、ネジの長さ

### スイッチソケットを使用せずキースイッチを直接PCBにはんだ付けする

キースイッチの足とPCBの穴の間にはんだを大量に流し込むことで、スイッチソケットを使用せずにキースイッチを付けることができます。

スイッチプレートをつけ忘れないよう注意してください。

### 高さの調整

スペーサーの長さを変えることで、モジュールごとに高さを調整できます。

例えば、メインモジュールと小指モジュールのスペーサーを長いものに変更すると、親指モジュールだけを相対的に低くすることができます。

また、z軸方向はスタンドオフの長さをメインプレートに比べて少し低くするといった工夫も可能です。親指プレートだけ choc にしてメインプレートに対して高さを抑えることもできます。

### チルトとテント

高さの調整の応用です。長さの異なるスペーサーを組み合わせることで、各モジュールのチルト、テント角度の調整ができます。

例えば、メインプレートはz軸方向の高さ調整が可能です。中心方向の2本のスタンドオフを高くし、中心に向かってチルトさせることができます。

PCBやプレートに負荷がかかるので、ネジを強く締めすぎないように気を付けてください。

### PCBの脱落防止

PCBとボトムプレートにはM1.4の穴が開いており、そこにネジとナットを入れることでPCBを支えることができます。

以下の写真を参考にお試しください。

  

### テープLEDの追加

追加で必要な部品 ：テープLED

テープLEDを追加できます。NeoPixcelの代わりにテープLEDを追加することも、NeoPixelとテープLEDの両方を実装することもできます。

標準ファームウェアでは6個のLEDを使用できます。テープLEDを使用するときはLEDが6個になるようにテープLEDを切断して使用してください。

### 数字行の削除

メインモジュール、小指モジュールのキー数を4行から3行に変更できます。
行を減らすには、スイッチプレートおよびPCBを切断します。

元に戻せないので慎重に判断してください。

### ロータリーエンコーダーの実装

ロータリーエンコーダーを使えるようにします。SHコネクタでProMicroの裏とロータリーエンコーダーを接続します。

### ロータリーエンコーダーの削除

メインモジュールのロータリーエンコーダーを削除できます。
ロータリーエンコーダーを削除するには、スイッチプレート、PCB、およびボトムプレートを切断します。

元に戻せないので慎重に判断してください。

### 拡張キーの削除

メインモジュールのロータリーエンコーダーの隣にある拡張キーを削除できます。
拡張キーを削除するには、スイッチプレート、PCB、およびボトムプレートを切断します。

拡張キーを削除するとロータリーエンコーダーも同時に削除されます。
ロータリーエンコーダーを使用して拡張キーを使用しない場合は、拡張キーを切り離さずにキースイッチを取り外す等で対応してください。

元に戻せないので慎重に判断してください。

### マイコンボード周辺部分の切り離し

メインモジュールにある Pro Micro 部分は切り離すことができます。内側にキーを追加したい場合やトラックボールを配置するなどこの部分が邪魔になる場合は切り離して、メインプレートとワイヤで配線することで別の場所に移動することができます。

1. 切り離し
2. メインプレートとマイコンボードの配線

 ###  互換モジュールの使用

各モジュールをPangaea keyboardと同じ規格で設計された物に入れ替えたり、モジュールを追加したりできます。

将来、モジュールの最も外側のキーが下方向に下がった部品も用意される予定です。

自分で互換モジュールを設計することも可能です。

※ 互換モジュールの設計については、「設計者向けガイド（執筆中）」を参照してください。不明点等はPangaea開発チームに問い合わせてください。

## さらなる改造

標準キット外の基板を用いた改造について説明します。

[準備](#準備) > [組み立て](#組み立て) > [ファームウェア](#ファームウェア) > [仕上げ](#仕上げ) > [調整
](#調整)  ( > [オプション機能](#オプション機能) > **さらなる改造**)

単純にテキスト入力だけなら標準キットで十分ですが、特定のアプリケーションやWeb会議などやはり専用のキーが欲しくなってりする場面が出てくると思います。
Pangaea は自由に拡張でき、かつ接続の標準インタフェースを定めているためパーツの交換が容易にできます。

ここではキーの追加、Rotary Encoder,OLED, Joy Stick, Dial switch の追加方法について説明します。

Pangaea の設計者は e3w2q さんです。e3w2qさんの有名な作品にSU120があります。SU120 と組み合わせることで Function key や Rotary Encoder などを追加することができます。

### キーの追加

キーを追加する方法です。

1. SU120を利用してキーの追加
2. QMK Firmware の対応

### ロータリーエンコーダの追加

ロータリーエンコーダを追加する方法です。

1. SU120を利用してロータリーエンコーダの追加
2. QMK Firmware の対応

### OLEDディスプレイの追加

OLEDディスプレイを追加する方法です。

1. OLEDディスプレイの取り付け
2. QMK Firmware の対応

---

以上。

[目次](#目次) > [準備](#準備) > [組み立て](#組み立て) > [ファームウェア](#ファームウェア) > [仕上げ](#仕上げ) > [調整](#調整)  ( > [オプション機能](#オプション機能) > [さらなる改造](#さらなる改造) )

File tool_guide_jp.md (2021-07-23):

[English](tool_guide.md) / [日本語](tool_guide_jp.md)

# 使用する道具、消耗品

## 調達製品例

調達するとよいものの一覧です。解説は下にまとめて記載します。

### 松コース（定番と思われる製品）

| 道具、消耗品 | 製品例 | 調達先の例 | 参考価格 |
| --- | --- | --- | --- |
| はんだこて | 白光 ダイヤル式温度制御はんだこて FX600 | https://www.amazon.co.jp/dp/B006MQD7M4 | 3,900円  |
| 交換用こて先 | 白光 こて先 2C型 T18-C2 | https://www.amazon.co.jp/dp/B004OR7UBM | 478円 |
| はんだこて台 | 白光(HAKKO) こて台 633-01 | https://www.amazon.co.jp/dp/B000TGNWCS | 1,680円  |
| はんだ吸取器 | サンハヤト はんだシュッ太郎NEO 45Wタイプ HSK-300 | https://www.amazon.co.jp/dp/B01FEV2BPG | 4,918円  |
| ニッパー | エンジニア マイクロニッパー NS-04 | https://www.amazon.co.jp/dp/B000TGJSWG | 1,414円  |
| 精密ドライバー +0番 | エンジニア +精密ドライバーセット 6本組 DM-20 | https://www.amazon.co.jp/dp/B06XXXVPRY | 807円 |
| テスター | OHM(オーム電機) デジタルマルチテスター TDB-401 (04-1891) | https://www.amazon.co.jp/dp/B001TVKWWU | 2,543円  |
| ハンダ | goot 精密プリント基板用はんだ SD-62 | https://www.amazon.co.jp/dp/B0029LGAMA | 255円 |
| エキポシ接着剤 2液混合タイプ | セメダイン 5分硬化型エポキシ系接着剤 ハイスーパー5 P15gセット CA-188 | https://www.amazon.co.jp/dp/B0036WHO0S | 566円 |
| マスキングテープ | 3M スコッチ 塗装用マスキングテープ 18mm×18m M40J-18 | https://www.amazon.co.jp/dp/B005JWNJZM | 95円 |
| 紙やすり | KAKURI 紙ヤスリMIXセット 12枚入 | https://www.amazon.co.jp/dp/B01ARIEU0A | 436円 |
| 太マジック | GSIクレオス ガンダムマーカー 塗装用 ブラック GM10 | https://www.amazon.co.jp/dp/B0113EW1GW | 270 |
| 計 | | | 17,362円 |

### 梅コース（価格優先）

| 道具、消耗品 | 製品例 | 調達先の例 | 参考価格 |
| --- | --- | --- | --- |
| はんだこて、交換用こて先、はんだこて台、ハンダ吸取器 | Beneges 温度調整 はんだごて セット | https://www.amazon.co.jp/dp/B077P4GMZW | 2,289円  |
| ニッパー | エンジニア マイクロニッパー NS-04  | https://www.amazon.co.jp/dp/B000TGJSWG | 1,414円  |
| 精密ドライバー +0番 | 精密ドライバーセット | ダイソー | 110円 |
| テスター | Crenova デジタルマルチメーター | https://www.amazon.co.jp/dp/B00KXX2OYY | 1,699円  |
| ハンダ | 電子工作用ハンダ（ヤニ入） | ダイソー | 110円 |
| エキポシ接着剤 2液混合タイプ | 強力接着剤 エキポシ2液混合タイプ | ダイソー | 110円 |
| マスキングテープ | | ダイソー | 110円 |
| 紙やすり | ホビー工作紙ヤスリ 6枚セット | ダイソー | 110円 |
| 太マジック | | ダイソー | 110円 |
| 計 | | | 6,052円  |

## 解説

### はんだこて

はんだこてとニッパーは100円ショップのものはおすすめしません。

[WEBはんだ付け講座 はじめに・・](https://noseseiki.com/kisokouza/01.html)より

> 現在、日本では趣味ではんだ付けされる方の大半が、温度調節機能のないハンダゴテを使用されています。こうしたハンダゴテはコテ先温度が450～550℃と高く上がりすぎます。このため、このハンダゴテを使ってはんだ付けしたものは、ほとんどがオーバーヒート状態になってしまいます。

ハンダ付けの経験があまりない、またはかなり前にやったという方は温度調整機能付きのものを用意されることを強くおすすめします。ちゃんとしたものを揃えたいという場合は、よくお勧めされる白光のはんだこてがよいと思います。

### 交換先こて先

はんだこてに最初から付いている円錐形のものは対象と点で当たるので熱が伝わりにくく、加熱不足ではんだを置いてしまうということがあるので、2Cのこて先に付け替え、面で加熱できるようにするとやりやすいです。

### はんだこて台

安全にはんだこてを置くために必要です。

### ハンダ吸取器または吸取線

ハンダ付けを失敗したときにないと困るので用意しておくとよいです。

### ニッパー

基板・ビスケットの切り離し、ダイオードの足・ピンヘッダのカットに使います。

ニッパーも100円ショップのものは以下の理由でおすすめしません。

- 切れ味があまり良くなく、ダイオードの足やピンヘッダが切りにくい
- 刃がツライチではないので、ギリギリに切れない

### テスター

キーが入力できない場合の問題切り分けに必要です。

導通モードがあればよいです。

### 電子工作用ハンダ

有鉛タイプが作業しやすいです。

SU120に使う部品に特段小さいものはないので1mmのものでも十分作業できますが、0.8mmだとはんだが溶けやすいようです。

### エポキシ接着剤 2液混合タイプ

Pro Microのもげ防止加工に使います。

### マスキングテープ

ハンダ付けで基板を裏返す際に部品を固定しておくのに使います。

## 参考になるWebページ

上の調達製品例・解説は個人の私見ですので、もう少し広く情報収集したい場合は以下のリンク先が参考になります。

- [Helix キーボードキットの製作に必要な工具メモ - GitHub](https://gist.github.com/mtei/6957107a676ddfa85bde0ae41f8fa849)
- [自作キーボードを作るために必要なもの - 自作キーボード温泉街の歩き方](https://salicylic-acid3.hatenablog.com/entry/2018/11/24/自作キーボードを作るために必要なもの)
- [自作キーボードの組み立てに使っている工具 | yfuku docs](https://yfuku.com/blog/keyboard/keybord_build_tool/)
- [elephant42 の組み立てかた#工具の準備 · illness072/elephant42](https://github.com/illness072/elephant42/blob/master/docs/build-guide.md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)
- [基礎からわかる！自キ入門講座 第8回「自作キーボードのつくりかた #2」 - YouTube](https://www.youtube.com/watch?v=LOC53FeU-QM)

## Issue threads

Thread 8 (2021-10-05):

Cannot hold the nuts that fix the connection plate to the bottom plate of the main module and the bolt may not be tightened. (ver. 0.2)

otahinosame, 2021-10-05:
メインモジュールのボトムプレートに小指/親指モジュールの接続プレートを固定するナットは、組み立て後は他のパーツに隠れるため工具で押さえつけるのが難しい。
固定ナットを調整のために緩めたあとに再度締めようとすると、空回りすることがある。
そうなると、一度分解して組み立て直す必要があり、面倒。

対策を考えて、パーツ設計ないし組み立て方に反映する必要があります。

対策案：
・ナットと接続プレートの間にスプリングワッシャーを挟む　→ 何も挟まないよりマシだが、不十分と感じる
・ゴムワッシャを挟む　→ 試してみたい

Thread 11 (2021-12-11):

Revision of the build guide as pointed out by the testers

e3w2q, 2021-12-11:
- [ ] Typo たくさん
- [ ] Display部の説明の違和感
- [ ] SMD diode の方向性の写真、説明の追加
- [ ] 基板とパーツの向きの説明で、リバーシブルの説明を追加
- [ ] 基板の角の斜線の二重線と、三重線の区別を確認する。その場合、説明を追加。PCBのデザインも要確認。
- [ ] 写真中のクラスタの位置が上下逆。要、写真の取り直しと差し替え。
- [ ] 上記の考え方として、diode, switch socketは裏、TRRS/Pro Microも裏を追加する。写真修正、説明追加
- [ ] AWG30電線の処理 (Wire stripper がない場合の処理の仕方を説明(ハンダゴテの熱 or カッター利用?)
- [ ] PCBの円形スペーサを写真から削除。どこにどの長さのスペーサを使うか写真で図示
- [ ] Bottom Plate の下の曲線側プレートのネジ穴がキツキツでドライバーで回して入れる必要あり
- [ ] 各プレート間の配線の長さは12cmくらいが良さそう。(少なくとも14cmは長すぎる状況)

etalli, 2021-12-12:
>SMD diode の方向性の写真、説明の追加

対応しました。reviewお願いします。

etalli, 2021-12-12:
＞ 写真中のクラスタの位置が上下逆。要、写真の取り直しと差し替え。

とりいそぎ説明のみ更新しました。後ほど機器が交換できて修理できたら写真を更新します。

etalli, 2021-12-12:
＞ 上記の考え方として、diode, switch socketは裏、TRRS/Pro Microも裏を追加する。写真修正、説明追加

説明のみ追加。サメさんとダブりあり。とりいそぎ。

etalli, 2021-12-13:
> 写真中のクラスタの位置が上下逆。要、写真の取り直しと差し替え。

写真を入れ替えました。壊れた機材の代替品は一日で到着でした。

etalli, 2021-12-13:
＞PCBの円形スペーサを写真から削除。どこにどの長さのスペーサを使うか写真で図示

写真を追加しました。PCBの円形スペーサの写真は不要と判断し削除しました。

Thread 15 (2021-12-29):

Screws and spacers interfere (ver. 0.3/1.0)

mokesura, 2021-12-29:
ver. 0.3/1.0の左手側を組み立ててみて、問題があると思った箇所を記載します。
問題は4つありますが、全てスペーサーやネジについてでしたので、まとめて一つのIssueに記載しています。
問題ごとに別のIssueに分けたほうがよいなどありましたらお知らせください。

## ProMicroをPCBの裏側につけた場合、左手側の6mmスペーサーが干渉します

ProMicroをPCBの裏側につけた場合、ProMicroと干渉して左手側の6mmスペーサーを取り付けることができません。
（以下の写真は右手側ですが、状況再現のために左手側のスペーサー、ProMicroの取り付け位置に取り付けています）

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

ProMicroを裏返し、右の穴に取り付ける場合はスペーサーとの干渉はなくなります。
その代わり、2.5mm厚コンスルーではボトムプレートの方に干渉します。
（写真ではわかりづらいですが、USBメスコネクタ部分とボトムプレートが当たっています）

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

PCBの表側にPro Microを取り付けた場合はこの干渉は発生しません。
解決方法として以下の3つが挙げられます。

1. 干渉する6mmスペーサーを使用しない
（押下される部分ではないので、もう1本の6mmスペーサーだけでも支えられるかと思います）
1.  ProMicroをPCBの表側につける
（その場合はProMicroカバーを取り付けない、あるいはProMicroカバーとPCBの間のスペーサーを6mmくらいにする）
1.  ProMicroを裏向きにつけ、1.5mm厚などの薄いコンスルーを用いる
（薄いコンスルーの入手性がよくないので、現実的ではない。2mmコンスルーで対応できるかどうかは未確認）

## この部分の6mmスペーサーを取り付けるネジが、低頭ネジだとスルーホールに干渉する

ProMicro取り付け部の6mmスペーサーを取り付けるネジが、低頭ネジだとスルーホールに干渉します。
この部分での拡張をしないか、なべネジで取り付ければ問題はないかと思います。

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

## ProMicro取り付け部とボトムプレート間のスペーサーが6mmだと足りない

これはスペーサーやワッシャの挟み方によるのかもしれませんが、ProMicro取り付け部とボトムプレート間のスペーサーが6mmだと若干浮いてしまっています。
ワッシャを1枚挟んで調整しています。

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

## 親指島のネジがキースイッチに干渉する

キースイッチによるのかもしれませんが、親指島の上部のネジ2箇所がキースイッチに干渉します。
（写真のキースイッチは、Gateron Milky Blackです）

キースイッチを削るまではしなくていいと思うのですが、ビルドガイドに一言あるとありがたいです（「ネジが干渉しますがそのままでも問題ありません。気になる方はキースイッチの隅を切るなどしてください」など）。

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

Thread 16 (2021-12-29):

Spelling discrepancies of build guide

mokesura, 2021-12-29:
ビルドガイド内に単語の表記ゆれが散見されます。
最終的にはどれかの単語にまとめたほうがいいかと思いますので、まとめ用のIssueを作成します。

alg0002, 2021-12-29:
いくつか表記揺れに気づいたので共有します。

 * Pro Micro / ProMicro / マイコン
 * 基板 / PCB
 * TRRS ジャック / TRRS / TRS/TRRSジャック
 * Firmware / firmware →カタカナにする？

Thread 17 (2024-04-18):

Need to update remap registration information

otahinosame, 2024-04-18:
@e3w2q
※下記対応の話とは別に、これを読まれていたら何らかの手段でリアクションいただけますと幸いです。

https://github.com/e3w2q/Pangaea-keyboard/tree/mainte_config

In order to keep up with the latest QMK, we have added support for info.json. This changes the encoder specification method, so the json for VIA/remap also needs to be changed to the ENCORDER_MAP compliant version. Therefore, remap registration information also needs to be updated.

最新のQMKに追従するため、info.json対応をしました。これによりencorder指定方法が変わりますので、VIA/remap用のjsonもENCORDER_MAP対応版に変更する必要があります。なので、remap登録情報も更新が必要です。

Since e3-san is the Pangaea maintainer for remap, I think e3-san needs to update the registration information.
Could you please update the remap?
After the remap information is updated, I will merge the ENCORDER_MAP compliant version into the master and create the tag.

remapのPangaeaメンテナはe3さんなので、e3さんが登録情報を更新する必要があるかと思います。
remapを更新していただけますか？
remap情報が更新できた後に、ENCORDER_MAP対応版をmasterにマージしてtag作成しようと思います。

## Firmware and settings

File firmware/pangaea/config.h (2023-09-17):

#pragma once

/* the frequency at which the switch matrix is being scanned.*/
//#define DEBUG_MATRIX_SCAN_RATE

/* key matrix size */
#define MATRIX_ROWS 5 * 2 // split keyboard
#define MATRIX_COLS 5 * 2 // duplex matrix

#define BOOTMAGIC_LITE_ROW 0
#define BOOTMAGIC_LITE_COLUMN 1

/* key matrix pin assign */
#define MATRIX_ROW_PINS { B4, B5, F4, F5, B6 }
#define MATRIX_COL_PINS { D4, C6, D7, E6, F6 }

/* COL2ROW, ROW2COL*/
// #define DIODE_DIRECTION COL2ROW

#define ENCODERS_PAD_A {D1}
#define ENCODERS_PAD_B {D0}

/* Split Keyboard specific options */
#define SOFT_SERIAL_PIN D2 /* serial communication pin */

// fix iPhone and iPad power adapter issue
// iOS device need lessthan 100
#define USB_MAX_POWER_CONSUMPTION 500

/* Debounce reduces chatter (unintended double-presses) - set 0 if debouncing is not needed */
#define DEBOUNCE 5

/* Mechanical locking support. Use KC_LCAP, KC_LNUM or KC_LSCR instead in keymap */
#define LOCKING_SUPPORT_ENABLE
/* Locking resynchronize hack */
#define LOCKING_RESYNC_ENABLE

#ifdef RGB_MATRIX_ENABLE
  #define DRIVER_LED_TOTAL 12
#endif

/* RGB LED options
 See https://docs.qmk.fm/#/feature_rgblight?id=changing-the-order-of-the-leds
*/
#undef WS2812_DI_PIN
#define WS2812_DI_PIN D3
//#define RGB_DI_PIN D3 // The pin connected to the data pin of the LEDs
#ifdef RGBLIGHT_ENABLE
  //#ifndef RGBLED_NUM
  #undef RGBLED_NUM
  #define RGBLED_NUM 12
  #define RGBLIGHT_SPLIT
  #define RGBLED_SPLIT { 6, 6 }
  #define RGBLIGHT_LED_MAP { 0,  1,  2,  3,  4,  5, \
                          11, 10,  9,  8,  7,  6 }
  /*** Effect and Animation Toggles */
  #define RGBLIGHT_EFFECT_ALTERNATING
  #define RGBLIGHT_EFFECT_BREATHING
  #define RGBLIGHT_EFFECT_CHRISTMAS
  #define RGBLIGHT_EFFECT_KNIGHT
  #define RGBLIGHT_EFFECT_RAINBOW_MOOD
  #define RGBLIGHT_EFFECT_RAINBOW_SWIRL
  #define RGBLIGHT_EFFECT_RGB_TEST
  #define RGBLIGHT_EFFECT_SNAKE
  #define RGBLIGHT_EFFECT_STATIC_GRADIENT
  #define RGBLIGHT_EFFECT_TWINKLE
  /*** Configuration */
  #define RGBLIGHT_LIMIT_VAL 128 // 255,The maximum brightness level
  #define RGBLIGHT_HUE_STEP 10 // The number of steps to cycle through the hue by
  #define RGBLIGHT_SAT_STEP 17 // The number of steps to increment the saturation by
  #define RGBLIGHT_VAL_STEP 17 // The number of steps to increment the brightness by
  #define RGBLIGHT_SLEEP // Not defined, If defined, the RGB lighting will be switched off when the host goes to sleep
  //#define RGBLIGHT_SPLIT // Not defined, If defined, synchronization functionality for split keyboards is added
  //#define RGBLIGHT_DEFAULT_MODE  RGBLIGHT_MODE_STATIC_LIGHT // The default mode to use upon clearing the EEPROM
  #define RGBLIGHT_DEFAULT_HUE 180 // (0:red, 180:blue) The default hue to use upon clearing the EEPROM
  #define RGBLIGHT_DEFAULT_SAT UINT8_MAX // (255) The default saturation to use upon clearing the EEPROM
  #define RGBLIGHT_DEFAULT_VAL RGBLIGHT_LIMIT_VAL // The default value (brightness) to use upon clearing the EEPROM
  #define RGBLIGHT_DEFAULT_SPD 0 // The default speed to use upon clearing the EEPROM
  //#define RGBLIGHT_DISABLE_KEYCODES // Not defined, If defined, disables the ability to control RGB Light from the keycodes. You must use code functions to control the feature
  /*** Effect and Animation Settigs */
  //#define RGB_MATRIX_STARTUP_SPD 127
#endif

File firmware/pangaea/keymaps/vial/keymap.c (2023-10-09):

/** Nov 21, 2022
 * Pangaea ver.1.2 for QMK 0.18.17
 * [Quantum Mechanical Keyboard Firmware](https://docs.qmk.fm/#/)
**/
/*
This program is free software: you can redistribute it and/or modify
it under the terms of the GNU General Public License as published by
the Free Software Foundation, either version 2 of the License, or
(at your option) any later version.

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
You should have received a copy of the GNU General Public License
along with this program.  If not, see <http://www.gnu.org/licenses/>.
*/

#include QMK_KEYBOARD_H

#define _QWERTY 0
#define _LOWER  1
#define _RAISE  2
#define _ADJUST 3

// Defines the keycodes used by our macros in process_record_user
enum custom_keycodes {
 QWERTY = SAFE_RANGE, // default layer
 LOWER,   // Layer1
 RAISE    // Layer2
};

#ifdef ENCODER_ENABLE
// Potentiometer, Rotary encoder
enum encoder_number {
 _1ST_ENC = 0,
 _2ND_ENC
};
#endif

#define DONTUSE _______

const uint16_t PROGMEM keymaps[][MATRIX_ROWS][MATRIX_COLS] = {
 [0] = LAYOUT(
  _______,_______,_______,_______,_______,_______,                                 _______,_______,_______,_______,_______,_______,
  KC_ESC ,KC_1   ,KC_2   ,   KC_3,   KC_4,   KC_5,                                    KC_6,   KC_7,   KC_8,   KC_9,   KC_0,KC_GRV ,
  KC_TAB ,KC_Q   ,KC_W   ,   KC_E,   KC_R,   KC_T,                                    KC_Y,   KC_U,   KC_I,   KC_O,   KC_P,KC_MINS,
  KC_LCTL,KC_A   ,KC_S   ,   KC_D,   KC_F,   KC_G,KC_VOLD,KC_VOLU, KC_PGUP,KC_PGDN,   KC_H,   KC_J,   KC_K,   KC_L,KC_SCLN,KC_QUOT,
  KC_LSFT,KC_Z   ,KC_X   ,   KC_C,   KC_V,   KC_B,KC_LBRC,KC_MUTE, KC_HOME,KC_RBRC,   KC_N,   KC_M,KC_COMM, KC_DOT,KC_SLSH,KC_RSFT,
          KC_LALT,KC_LGUI,  LOWER, KC_SPC, KC_DEL,                                  KC_EQL, KC_ENT,  RAISE,KC_BSPC,KC_RGUI,
                  _______,_______,_______,                                                 _______,_______,_______
  ),
  [_LOWER] = LAYOUT(
  _______,_______,_______,_______,_______,_______,                                 _______,_______,_______,_______,_______,_______,
  _______,_______,_______,_______,_______,_______,                                 _______,_______,_______,_______,_______,_______,
    KC_F1,  KC_F2,  KC_F3,  KC_F4,  KC_F5,  KC_F6,                                   KC_F6,  KC_F7,  KC_F8,  KC_F9,   KC_0,_______,
   KC_GRV,KC_EXLM,  KC_AT,KC_HASH, KC_DLR,KC_PERC,_______, _______,_______,_______,KC_CIRC,KC_AMPR,KC_ASTR,KC_LPRN,KC_RPRN,KC_TILD,
  _______,_______,_______,_______,_______,_______,QK_BOOT,_______, _______,_______,_______,KC_UNDS,KC_PLUS,KC_LCBR,KC_RCBR,KC_PIPE,
          _______,_______,_______,_______,_______,                                 _______,_______,_______,_______,_______,
                  _______,_______,_______,                                                 _______,_______,_______
   ),
  [_RAISE] = LAYOUT(
  _______,_______,_______,_______,_______,_______,                                 _______,_______,_______,_______,_______,_______,
  _______,_______,_______,_______,_______,_______,                                 _______,_______,_______,_______,_______,_______,
    KC_GRV,  KC_1,   KC_2,   KC_3,   KC_4,   KC_5,                                    KC_6,   KC_7,   KC_8,   KC_9,   KC_0,_______,
    KC_F1,  KC_F2,  KC_F3,  KC_F4,  KC_F5,  KC_F6,_______, _______,_______,_______,_______,KC_LEFT,KC_DOWN,  KC_UP,KC_RGHT,_______,
    KC_F7,  KC_F8,  KC_F9, KC_F10, KC_F11, KC_F12,QK_BOOT,_______, _______,_______,KC_PLUS,KC_MINS, KC_EQL,KC_LBRC,KC_RBRC,KC_BSLS,
          _______,_______,_______,_______,_______,                                 _______,_______,_______,_______,_______,
                  _______,_______,_______,                                         _______,_______,_______
  )
};


// Layers and macros
bool process_record_user(uint16_t keycode, keyrecord_t *record) {
#ifdef CONSOLE_ENABLE
    uprintf("keycode：%u, col: %u, row: %u, pressed: %u\n", \
             keycode, record->event.key.col, record->event.key.row, record->event.pressed);
#endif
  switch (keycode) {
    #ifdef OLED_ENABLE
      if (record->event.pressed) {
            key_count++; // count up key press
            set_keylog(keycode, record); // display key code
      }
    #endif
   case QWERTY:
      if (record->event.pressed) {
        set_single_persistent_default_layer(_QWERTY);
      }
      return false;
      break;
    case LOWER:
      if (record->event.pressed) {
        layer_on(_LOWER);
        //update_tri_layer(_LOWER, _RAISE, _ADJUST);
      } else {
        layer_off(_LOWER);
        //update_tri_layer(_LOWER, _RAISE, _ADJUST);
      }
      return false;
      break;
    case RAISE:
      if (record->event.pressed) {
        layer_on(_RAISE);
        //update_tri_layer(_LOWER, _RAISE, _ADJUST);
      } else {
        layer_off(_RAISE);
        //update_tri_layer(_LOWER, _RAISE, _ADJUST);
      }
      return false;
      break;
    //case ADJUST:
      //if (record->event.pressed) {
        //layer_on(_ADJUST);
      //} else {
        //layer_off(_ADJUST);
      //}
      //return false;
      //break;
  }
  return true;
}

const uint8_t rt_matrix[][2][2] = {
  {{0, 9}, {1, 9}},
  {{5, 9}, {6, 9}}
};

#ifdef ENCODER_ENABLE
// Rotary encoder
bool encoder_update_user(uint8_t index, bool clockwise) {
  keypos_t key;
  int cw = clockwise ? 1 : 0;
  key.row = rt_matrix[index][cw][0];
  key.col = rt_matrix[index][cw][1];
  uint8_t layer = layer_switch_get_layer(key);
  uint16_t keycode = keymap_key_to_keycode(layer, key);
  tap_code16(keycode);
  return false;
}
#endif

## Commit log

2021-07-25 Update pangaea-specification-1.0.md
    Added switches.
2021-07-28 fix LAYOUT macro function
    disabled VIA, and changed default keymap for debugging.
    [keymap.c]
2021-09-09 Upload PCB
    [prototyper-bottom-draft.kicad_pcb, prototyper-bottom.kicad_pcb, prototyper-pcb-draft.kicad_pcb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]
2021-12-12 Added SMD diode photo and explanation.
2021-12-12 Update build_guide_jp.md
    ・用語確認の写真の位置と改行を修正
    ・不要と思われる｀｀の削除
2021-12-13 Relapaced left handed wired image
2021-12-13 replaced left hand wired picture
2021-12-13 removed a picture of SMD diode
2021-12-13 Added picture of PCB wrench
2021-12-16 Update build_guide_jp.md
    不要と思われる記号を削除
2022-11-12 enable LED effect
2022-12-06 Create 3mm-8mm-PCB.drawio.png
    png
2022-12-24 updated wired expression
2023-03-01 append about M1.4 holes
2023-03-05 Update bom_list_jp.md
    add M1.4 screw and nut

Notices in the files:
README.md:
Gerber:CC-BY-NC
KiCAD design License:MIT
